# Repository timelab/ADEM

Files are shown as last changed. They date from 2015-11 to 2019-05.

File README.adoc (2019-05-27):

= Timelab ADEM project



The http://www.timelab.org/[Timelab] ADEM project enables cyclists to measure particulate matter (PM~1~ and PM~2.5~). The air quality estimate based on these measurements is displayed on the device, temporarily stored and sent via WiFi to a central data collection service.

The aim of this project is to create a low-cost open-source DIY hardware and firmware kit that is modular and adjustable, can be locally reproduced and repaired.

This git repository hosts the hardware designs, firmware and technical documentation for the ADEM device. You can find the documentation at: https://github.com/timelab/ADEM/tree/master/docs[]

More information related to this project is available from the project's wiki at: http://wiki.timelab.org/wiki/A.D.E.M[]

We welcome feedback and contributions.

ADEM logo

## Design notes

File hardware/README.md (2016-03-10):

# Hardware

The project uses the SparkFun Thing. This ESP8266 based Wi-Fi controller development board runs the A.D.E.M. firmware and conveniently hosts a LiPo battery management system that is key in the mobility aspect of this project. Apart from the headers for the SparkFun Thing, the project's printed circuit board has room for a GPS module, temperature and pressure sensors and connections to external parts like the PPD40NS dust sensor.

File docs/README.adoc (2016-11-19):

= ADEM project documentation
:author: The Timelab ADEM project team
:version: 0.1 draft
:data-uri:
:doctype: book
:encoding: UTF-8
:toc:
:toclevels: 2

Welcome to the ADEM project documentation.

The aim of this project is to create a device that collects air polution data (PM1 and PM2.5 fine dust) and is mounted on bicycles to crowdsource factual air pollution information in and around the city of Ghent, Belgium.

The hardware and firmware design is modular and extendable. The device can be locally reproduced and repaired.

:numbered:
:leveloffset: 1
include::01-getting-started.adoc[]

include::02-arduino-setup.adoc[]

include::03-hardware.adoc[]

include::04-prototype.adoc[]

include::05-firmware-design.adoc[]

:numbered!:
[appendix]
include::0a-questions-and-answers.adoc[]

[appendix]
include::TODO.adoc[]

This is a work in progress so feel free to ask for clarification through GitHub's
https://github.com/timelab/ADEM/issues[issue interface] or even better,
send us updates through GitHub's
https://github.com/timelab/ADEM/pulls[pull request interface].

ADEM logo

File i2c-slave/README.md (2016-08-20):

# i2c-gps
I2C GPS interface for arduino mini pro with low power support

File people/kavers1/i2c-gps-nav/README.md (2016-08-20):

# i2c-gps-nav
MultiWii I2C GPS Nav module with RGB Debug Light / Improved Sonar

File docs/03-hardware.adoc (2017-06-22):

= Hardware

The project uses the SparkFun ESP8266 Thing Development board.

This ESP8266 based WiFi controller development board runs the ADEM firmware and conveniently hosts a LiPo battery management system that is key in the mobility aspect of this project. Apart from the headers for the SparkFun Thing, the project's printed circuit board has room for a GPS module, temperature and pressure sensors and connections to external parts like the PPD40NS dust sensor.

== Bill Of Materials

Listed prices are individual prices, not volume prices.

=== Mandatory components
[options="header"]
|=================================================================================================================
| Function                  | Component / Chip          | Price indication  |   Typical Power Draw - On / (deep sleep)  | Datasheet / Tutorial / Info / Example

| Microcontroller           | SparkFun ESP8266 Thing    | (15.95€ sparkfun) |
https://www.hackster.io/fablabeu/esp8266-thing-by-sparkfun-982bc6[100+mA]  (8mA) | https://cdn.sparkfun.com/datasheets/Wireless/WiFi/ESP8266ThingV1.pdf[datasheet]
https://www.sparkfun.com/products/13231[link] /
https://learn.sparkfun.com/tutorials/esp8266-thing-hookup-guide/all[tutorial]

| Accelerometer             | GY-521 / MPU6050          | (2.83€ banggood)  | 500uA (10uA) |
http://store.invensense.com/datasheets/invensense/MPU-6050_DataSheet_V3%204.pdf[datasheet]
http://playground.arduino.cc/Main/MPU-6050[arduino]

| Barometer                 | BMP180                    | (2.04 € banggood) | 5uA |
https://www.adafruit.com/datasheets/BST-BMP180-DS000-09.pdf[datasheet]

| Battery                   |                           |                   ||
EACHINE 3.7V 500mAh 25C

| Buzzer                    | KY-006                    | (1.44€ banggood)  ||
Xinda active (?) buzzer
https://tkkrlab.nl/wiki/Arduino_KY-006_Small_passive_buzzer_module[info]
http://learn.linksprite.com/arduino/sensors-kit-for-arduino/ky006-buzzer-module/[tutorial]
https://s3.amazonaws.com/linksprite/Arduino_kits/advanced_sensors_kit/KY006+code.pdf[example]

| Fine Dust Meter           | PPD42                     | ($15.90 seeed)                  | http://www.davidholstius.com/tag/ppd42ns/[90mA] |
http://sca-shinyei.com/pdf/PPD42NS.pdf[datasheet]
http://www.takingspace.org/wp-content/uploads/ShinyeiPPD42NS_Deconstruction_TracyAllen.pdf[info]
http://www.howmuchsnow.com/arduino/airquality/grovedust/[tutorial]
http://www.davidholstius.com/2012/06/12/this-side-up/[tips]

| GPS                       | XM37-1612 / GY-NEO6MV2    | (11.66€ banggood) | http://www.resistorpark.com/arduino-gps-gy-neo6mv2/[45uA] (0.02uA) |
https://www.iprototype.nl/docs/gps-LS20031-datasheet-gyneo6mv2.pdf[datasheet]
https://www.u-blox.com/sites/default/files/products/documents/NEO-6_ProductSummary_%28GPS.G6-HW-09003%29.pdf[product sheet]
https://www.u-blox.com/sites/default/files/products/documents/LEA-NEO-MAX-6_HIM_%28UBX-14054794%29.pdf[product family sheet]
https://www.u-blox.com/sites/default/files/products/documents/u-blox6_ReceiverDescrProtSpec_%28GPS.G6-SW-10018%29_Public.pdf[protocol spec]
https://www.u-blox.com/sites/default/files/products/documents/u6-PowerMgt_AppNote_%28GPS.G6-X-10014%29.pdf[power management]

| Humidity                  | HTU21D                    |                   | | https://www.sparkfun.com/products/retired/12064

| RGB Led                   | NeoPixel WS2812 8xled     | (2.40€ banggood)  | https://learn.adafruit.com/adafruit-neopixel-uberguide/power[<60mA] |
High Density Neopixel 8x LED

| Helper microcontroller | Arduino Pro Mini 3.3V | (11.79€ banggood)  |
http://www.whizzy.org/2015/06/howto-very-low-power-usage-on-pro-mini-v2-arduino-clone/[7mA-] http://forum.arduino.cc/index.php?topic=141759.0[9mA]|https://www.arduino.cc/en/Main/ArduinoBoardProMini[info]
|

TOTAL (est.) | | 64.01€ | >200mA | with 500mAh batt -> autonomy: 2,5hrs

|=================================================================================================================

=== Optional components
[options="header"]
|=================================================================================================================
| Function                  | Component / Chip          | Price indication  | Datasheet / Tutorial / Info
| Bluetooth                | HC05 / BC417              | (4.91€ banggood)  |
https://www.olimex.com/Products/Components/RF/BLUETOOTH-SERIAL-HC-06/resources/hc06.pdf[datasheet]

| Memory I2C                | AT24C512C                 | (0.8€ digikey)    |
http://www.atmel.com/devices/AT24C512C.aspx[link]

|=================================================================================================================

ADEM logo

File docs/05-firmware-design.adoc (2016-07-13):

= Firmware design

== Diagram

image::https://drive.google.com/file/d/0B5B2OKuFeGQfSWpKemVRNHZqeDg/view?usp=sharing[alt="Code Diagram", link="https://drive.google.com/file/d/0B5B2OKuFeGQfSFFJQkZjZVJLMGM/view?usp=sharing", align="center"]

== State machine

The state machine is part of the main loop and simply calls the specific state _loop_ code (e.g. +sleep_state()+) or handles a state transition (e.g. +start_to_sleep()+).

The current design is a simplified version, we expect additional states to be required in the future (e.g. for deep sleep, in-house measuring, etc.)

== States

These are the states the main loop controls.

 - START -> SLEEP
 - SLEEP
 - CONFIG
 - GPSTEST
 - COLLECT
 - WIFITEST
 - UPLOAD
 - RESET -> START

The conditional decisions made during a state are performed within the state _loop_. We defined specific functions for these inner loops (e.g. +sleep_state()+ or +collect_state()+).

== State transitions

Additionally when we move from one state to another state in the state machine, we require some things to happen. E.g. enable the sensors, or disconnect the GPS module. For this the state-machine will call specific _transition_ functions (e.g. +start_to_sleep()+ or +sleep_to_gpstest()+).

It is these functions that perform the most work. The state machine itself only directs to a state _loop_ or a transition _call_.

Some of these transitions do not need anything specific to happen.

=== Tasks

During the main loop, the scheduler also preserves time for other tasks to perform actions. These tasks allow e.g. the accelerator sensor to collect new data and update information that can influence the state machine.

Typically each sensor has its own task, however they may not be running the whole time but only in a specific state (e.g. COLLECT):

 - accelerator _(always enabled)_
 - barometer _(enabled in COLLECT state)_
 - gps _(enabled in GPSTEST and COLLECT state)_
 - humidity _(enabled in COLLECT state)_
 - particulate _(enabled in COLLECT state)_

== Pseudo-code

Below was our first design of the state machine. It may help in understand what is going on underneath.
Today this code is properly split into different functions and the state machine is clear an concise.

=== GLOBAL

----
Create accelerometer sensor object
Create barometer sensor object
Create buzzer object
Create gps sensor object
Create humidity sensor object
Create led object
Create particulate sensor object
Create scheduler
----

=== SETUP

----
Set STATE to START

Setup serial output

Create running accelerometer task (1s)
Create suspended barometer task (1m)
Create suspended gps task (1s)
Create suspended humidity task (1m)
Create suspended particulate task (30s)
Create suspended wifiap task
Create suspended wificlient task

Set STATE to SLEEP
----

=== LOOP

----
if STATE == SLEEP:

    if accelerometer.moving:
        Set STATE to GPS_START
        Run gps.begin
        Activate gps task

        Set STATE to GPS_TEST

    else:

        if NOT buffer.empty:
            Set STATE to WIFI_START
            Run wificlient.begin
            Activate wificlient task

            Set STATE to WIFI_TEST

        elif accelerometer.shaking:
            Set STATE to AP_START
            Run wifiap.begin
            Activate wifiap task

            Set STATE to CONFIG

elif STATE == CONFIG:

    if finished or timeout or canceled:
        Set STATE to AP_STOP
        Suspend wifiap task
        Run wifiap.end

        Set STATE to SLEEP

elif STATE == GPS_TEST:

    if accelerometer.moving:
        if gps.ready:
            Set STATE to COLLECT_START
            Run barometer.begin
            Activate barometer task
            Run humidity.begin
            Activate humidity task
            Run particulate.begin
            Activate particulate task

            Set STATE to COLLECT

    else:
        Set STATE to GPS_STOP
        Suspend barometer task
        Run barometer.end
        Suspend humidity task
        Run humidity.end
        Suspend particulate task
        Run particulate.end
        Suspend gps task
        Run gps.end

        Set STATE to SLEEP

elif STATE == COLLECT:

    Write sensor data to datastore

    if NOT accelerometer.moving or NOT gps.ready:
        Set STATE to GPS_TEST

elif STATE == WIFI_TEST:

    if wifi.fix:
        Set STATE to UPLOAD

    if accelerometer.moving OR buffer.empty or wifi.timeout:
        Set STATE to WIFI_STOP
        Suspend wificlient task
        Run wificlient.end

        Set STATE to SLEEP

elif STATE == UPLOAD:

    // Upload action finishes successfully or times out
    Create JSON of X records
    Send to Server
    Empty datastore

    Set STATE to WIFI_TEST

// LED remembers previous state and acts on state-changes
led.update()

scheduler.tick()
----

ADEM logo

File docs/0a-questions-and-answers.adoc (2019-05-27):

= Questions and Answers

== What are we measuring at what frequency ?

[options="header", width="100%"]
|============================================================================================
| Information                                        | Sensor                | Frequency
| Moving                                             | Accelerometer         | interrupt
| Shaking                                            | Accelerometer         | interrupt
| Time                                               | GPS                   | 1 sec
| Location (longitude/latitude)                      | GPS                   | 1 sec
| Particulate matter PM1                             | Particulate           | 20 secs
| Particulate matter PM2.5                           | Particulate           | 20 secs
| Humidity                                           | Humidity              | 1 min
| Temperature                                        | Humidity              | 1 min
| Pressure                                           | Barometer             | 1 min
| Temperature                                        | Barometer             | 1 min
| Altitude (optional)                                | GPS                   | N/A
| Speed (optional)                                   | GPS                   | N/A
| Temperature                                        | Accelerometer         | N/A
| Acceleration                                       | Accelerometer         | N/A
| Gyroscope                                          | Accelerometer         | N/A
|============================================================================================

== Will we use the physical on/off switch of the ESP8266 Thing ?

This is unclear yet. We might add this, but it will not be part of the Minimal Viable Product.

== How will the temperature, humidity and pressure sensors get outside information ?

The casing cannot be completely sealed to get usable humidity and pressure readings. However, we would like to have a water-resistant device to avoid internal condensation and/or rust. It definitely has to sustain all weather conditions. *TBD*

== Can we still make changes to the PCB design ?

At the moment changes to the PCB design are possible. Once we order the first batch of PCB printers, we have to be careful in making new changes.

== What are the essential parts for a release ?

The Minimal Viable Product would consist of the following sensors and compontents:

 - Accelerometer sensor
 - GPS
 - Humidity sensor
 - Barometer sensor
 - Particulate matter sensor

In future revisions (betas) we expect the following additional components:

 - I2C memory
 - Battery
 - Buzzer
 - Bluetooth (unlikely, WIFI and serial should be sufficient)
 - Casing

== Is the JSON interface to the back-end service already defined ?

Not in detail.

We already established that sensor-records will be stored in memory in binary form in a ring-buffer. When the device is not moving, a WIFI fix is obtained and records are uploaded (and buffer emptied). These records will store sensor id information, timing and sensor data. Since the GPS frequency is intermitted with sensor data the records can be properly timestamped.

This ensures efficient use of scarce memory, while retaining augmented information to the back-end.

ADEM logo

== Will the project make use of the newer and faster ESP32 ?

The ESP8266 has its limits. We have ran into problems with the amount of RAM and the available number of I/O pins. In the current stage of the project we are using a secondary processor (AVR) as a serial-to-I2C bridge for the GPS. This could probably be eliminated when switching to ESP32.

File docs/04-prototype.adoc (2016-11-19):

= Prototype design

== Serial baudrate

- For the UART0 serial output, we use the default boot mode baudrate of *74880*.
  This helps to use a single setup for debugging boot mode and firmware.

- For the SoftwareSerial interface to the GPS module, we use the default baudrate of *9600*.
  (Up for debate)

NOTE: For uploading new firmware, the baudrate can go up to *460800*. The baudrate can be selected from the Arduino IDE (Sketch).

== Firmware boot mode information
If you have issues running your firmware, you will see a message like this:

----
 ets Jan  8 2013,rst cause:2, boot mode:(1,6)
----

There is a small overview of the different cases:

.reset causes
[options="header"]
|=========================
| code | reset cause
| 0    | unknown
| 1    | normal boot
| 2    | reset pin
| 3    | software reset
| 4    | watchdog reset
|=========================

.boot mode
[options="header"]
|==============================
| code | description
| 0    | invalid
| 1    | download from UART0
| 2    | invalid
| 3    | boot from flash
| 4-7  | boot from SD-card
|==============================

////
.reset info
[options="header"]
|=================================================================================================
| code | name                    | reason
| 0    | REASON_DEFAULT_RST      | normal startup by power on
| 1    | REASON_WDT_RST          | hardware watch dog reset
| 2    | REASON_EXCEPTION_RST    | exception reset, GPIO status won’t change
| 3    | REASON_SOFT_WDT_RST     | software watch dog reset, GPIO status won’t change
| 4    | REASON_SOFT_RESTART     | software restart ,system_restart , GPIO status won’t change
| 5    | REASON_DEEP_SLEEP_AWAKE | wake up from deep-sleep
| 6    | REASON_EXT_SYS_RST      | external system reset
|=================================================================================================
////

== Pin assignments

Below pins are based on the SparkFun ESP8266 Thing Development board.

.Unfinished Fritzing diagram
image::https://drive.google.com/file/d/0B5B2OKuFeGQfWjY5S21PNXlLc1k/view?usp=sharing[alt="Fritzing diagram", link="https://drive.google.com/file/d/0B5B2OKuFeGQfWjY5S21PNXlLc1k/view?usp=sharing"]

=== Summary

- Pin D0: GPS RX (+ Buzzer)
- Pin D2: I2C SDA
- Pin D4: GPS TX
- Pin D5: NeoPixel (+ Onboard LED)
- Pin D12: PPD42 PM1
- Pin D13: PPD42 PM2.5
- Pin D14: I2C SCL
- Pin D16: (Deep Sleep) -> Usable ?
- Pin A0: PPD42 A

=== Detailed ESP8266

.ESP8266 I²C Header
[options="header"]
|==============================================================================
| Pin Name  | Description                             | Assignment
| GND       | Ground (0V)                             | ->GND line
| 3V3       | 3.3V                                    | ->3V3 line
| SDA (D2)  | I²C SDA (UART1 out: +Serial1+)          | ->SDA bus
| SCL (D14) | I²C SCL                                 | ->SCL bus
|==============================================================================

.ESP8266 UART0 Header
[options="header"]
|==============================================================================
| Pin Name  | Description                             | Assignment
| DTR (D0b) | Data Ready (Auto Reset / D0 Buffer)     |
| TXO (D7)  | UART transmit (+Serial+)                | ->UART0 out
| RXI (D8)  | UART receive (+Serial+)                 | ->UART0 in
| 3V3       | (Not Connected)                         |
| NC        | (Not Connected)                         |
| GND       | Ground (0V)                             | ->UART GND
|==============================================================================

.ESP8266 I/O Pins
[options="header"]
|==============================================================================
| Pin Name  | Description                             | Assignment
| GND       | Ground (0V)                             |
| VIN       | USB 4.5V or LiPo 3.7V                   |
| 5 (D5)    | On-board LED                            |
| 0 (D0)    |                                         | ->NeoPixel
| 4 (D4)    |                                         | ->GPS TX
| 13 (D13)  |                                         | ->PPD42 +PM25_SENSOR+
| 12 (D12)  |                                         | ->PPD42 +PM1_SENSOR+
| XPD (D16) | (Deep Sleep)                            |
| ADC (A0)  | (10-bit 1V)                             | ->PPD42 +A_SENSOR+
| EN        | Enable PIN                              |
|==============================================================================

=== Detailed Components

.PPD42NS (Fine dust meter)
[options="header"]
|==============================================================================
| Pin Name  | Description                             | Assignment
| 1         | Ground                                  | ->GND line
| 2         | Output P2 +PM25_SENSOR+                 | ->D13
| 3         | Vcc (5V, 90mA)                          | ->3V3 line
| 4         | Output P1 +PM1_SENSOR+                  | ->D12
| 5         | Input (T1) +A_SENSOR+, threshold for P2 | ->ADC
|==============================================================================

.GY-NEO6MV2 (GPS)
[options="header"]
|==============================================================================
| Pin Name  | Description                             | Assignment
| VCC       |                                         | ->3V3 line
| RX        |                                         |
| TX        |                                         | ->D4
| GND       | Ground (0V)                             | ->GND line
|==============================================================================

.NeoPixel (LED)
[options="header"]
|==============================================================================
| Pin Name  | Description                             | Assignment
| GND       | Ground (0V)                             | ->GND line
| Din       | Input signal                            | ->D0
| 5V        | Vcc (5V, ?mA)                           | ->3V3 line
|==============================================================================

.BMP180 (Barometer)
[options="header"]
|==============================================================================
| Pin Name  | Description                             | Assignment
| VIN       |                                         | ->3V3 line
| GND       |                                         | ->GND line
| SCL       |                                         | ->SCL bus
| SDA       |                                         | ->SDA bus
|==============================================================================

.HTU21D (Humidity/Temperature meter)
[options="header"]
|==============================================================================
| Pin Name  | Description                             | Assignment
| CL        |                                         | ->SCL bus
| DA        |                                         | ->SDA bus
| -         |                                         | ->GND line
| +         |                                         | ->3V3 line
|==============================================================================

.IGT/MPU (Accelerometer)
[options="header"]
|==============================================================================
| Pin Name  | Description                             | Assignment
| INT       |                                         |
| AD0       |                                         |
| XCL       |                                         |
| XDA       |                                         |
| SDA       |                                         | ->SDA bus
| SCL       |                                         | ->SCL bus
| GND       |                                         | ->GND line
| VCC       |                                         | ->3V3 line
|==============================================================================

=== Constraints

During testing we discovered some constraints to used pins.

NOTE: TODO: Describe the known issues here ? (Lieven)

ADEM logo

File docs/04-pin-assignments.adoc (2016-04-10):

= ESP8266 pin assignments

== Breadboard prototype Dag

Below pins are based on the SparkFun ESP8266 Thing.

.ESP8266 I²C Header
[options="header"]
|==============================================================================
| Pin Name  | Description                             | Assignment
| GND       | Ground (0V)                             | ->GND line
| 3V3       | 3.3V                                    | ->3V3 line
| SDA (D2)  | I²C SDA (UART2 out: +Serial1+)          | ->SDA bus
| SCL (D14) | I²C SCL                                 | ->SCL bus
|==============================================================================

.ESP8266 UART1 Header
[options="header"]
|==============================================================================
| Pin Name  | Description                             | Assignment
| DTR       | Data Ready (Auto Reset / D0 Buffer)     |
| TXO (D7)  | UART transmit (+Serial+)                | ->UART1 out
| RXI (D8)  | UART receive (+Serial+)                 | ->UART1 in
| 3V3       | (Not Connected)                         |
| NC        | (Not Connected)                         |
| GND       | Ground (0V)                             | ->UART GND
|==============================================================================

.ESP8266 I/O Pins
[options="header"]
|==============================================================================
| Pin Name  | Description                             | Assignment
| GND       | Ground (0V)                             |
| VIN       | USB 4.5V or LiPo 3.7V                   |
| 5 (D5)    | On-board LED ->Free                     |
| 0 (D0)    |                                         | ->NeoPixel
| 4 (D4)    |                                         | ->GPS TX
| 13 (D13)  |                                         | ->PPD42 +PM25_SENSOR+
| 12 (D12)  |                                         | ->PPD42 +PM10_SENSOR+
| XPD (D16) | (Deep Sleep)                            |
| ADC (A0)  | (10-bit 1V)                             | ->PPD42 +A_SENSOR+
| EN        | Enable PIN                              |
|==============================================================================

.Unassigned
 - BT_RX
 - BT_TX
 - INT
 - BUZZ

== Components

.PPD42NS (Fine dust meter)
[options="header"]
|==============================================================================
| Pin Name  | Description                             | Assignment
| 1         | Ground                                  | ->GND line
| 2         | Output P2 +PM25_SENSOR+                 | ->D13
| 3         | Vcc (5V, 90mA)                          | ->3V3 line
| 4         | Output P1 +PM10_SENSOR+                 | ->D12
| 5         | Input (T1) +A_SENSOR+, threshold for P2 | ->ADC
|==============================================================================

.GY-NEO6MV2 (GPS)
[options="header"]
|==============================================================================
| Pin Name  | Description                             | Assignment
| VCC       |                                         | ->3V3 line
| RX        |                                         |
| TX        |                                         | ->D4
| GND       | Ground (0V)                             | ->GND line
|==============================================================================

.NeoPixel (LED)
[options="header"]
|==============================================================================
| Pin Name  | Description                             | Assignment
| GND       | Ground (0V)                             | ->GND line
| Din       | Input signal                            | ->D0
| 5V        | Vcc (5V, ?mA)                           | ->3V3 line
|==============================================================================

.BMP180 (Barometer)
[options="header"]
|==============================================================================
| Pin Name  | Description                             | Assignment
| VIN       |                                         | ->3V3 line
| GND       |                                         | ->GND line
| SCL       |                                         | ->SCL bus
| SDA       |                                         | ->SDA bus
|==============================================================================

.HTU21D (Humidity/Temperature meter)
[options="header"]
|==============================================================================
| Pin Name  | Description                             | Assignment
| CL        |                                         | ->SCL bus
| DA        |                                         | ->SDA bus
| -         |                                         | ->GND line
| +         |                                         | ->3V3 line
|==============================================================================

.IGT/MPU (Accelerometer)
[options="header"]
|==============================================================================
| Pin Name  | Description                             | Assignment
| INT       |                                         |
| AD0       |                                         |
| XCL       |                                         |
| XDA       |                                         |
| SDA       |                                         | ->SDA bus
| SCL       |                                         | ->SCL bus
| GND       |                                         | ->GND line
| VCC       |                                         | ->3V3 line
|==============================================================================

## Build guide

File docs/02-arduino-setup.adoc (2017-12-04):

= Arduino setup

The firmware is written in Arduino.

== Installing the ESP8266 Arduino Addon

Follow the SparkFun tutorial on how to install the ESP8266 to your Arduino IDE:
https://learn.sparkfun.com/tutorials/esp8266-thing-hookup-guide/installing-the-esp8266-arduino-addon

== Cloning the ADEM GitHub repository

=== Installing Git

- Sign-up for a GitHub account at https://github.com/[]

- Install git on your PC

  * For Debian/Ubuntu:

    $ sudo apt-get install git

  * For Fedora/RHEL/CentOS:

    $ sudo yum install git

  * For Windows:

    1. Download and install from https://git-scm.com/downloads

    2. If you are editing code, make sure that your editor or IDE does not modify line-endings (this would make it look like unmodified files have been changed, and/or results in extra newlines under Linux).
       JetBrains IntelliJ IDEA is an example of a multi-platform IDE which can work with GitHub, and provide structure to the codebase.

- Set your GitHub and e-mailadress

  $ git config --global user.name "John Doe"
  $ git config --global user.email johndoe@example.com

=== Cloning the repository

You can make a local copy of the ADEM project code by running the following git command:

  $ git clone git@github.com:timelab/ADEM.git

== Contributing code

=== Forking
If you have a github account, you can contribute code to the ADEM project. Go to https://github.com/timelab/ADEM and *fork* the project to your GitHub profile. Then add it as a separate remote (stored in _.git/config_).

    $ git remote add yourgitusername https://github.com/yourgitusername/ADEM

If you use SSH keys, use:

    $ git remote add yourgitusername git@github.com:yourgitusername/ADEM.git

Update:

    $ git remote update

This way you can create pull-requests by modifying your local copy and pushing it to your personal GitHub profile.
Afterwards, the GitHub web-interface proposes to create a pull-request. It helps if you use different branches for pushing changes.

More information regarding the use of Git is available from: http://www.git-scm.com/book/en/v1/Git-Basics
The forking and contributing aspect is handled on: https://www.git-scm.com/book/en/v2/GitHub-Contributing-to-a-Project

More information regarding the use of GitHub is available from: https://guides.github.com/activities/hello-world/

=== Git daily use

Show the status of your local repository, you can do this any time:

    $ git status

When you want to add or change code, *make a new branch first*:

    $ git checkout -b <name of your branch>

Edit the files in you local copy with your editor of choice. After creating a new file or folder, add it so git can start tracking it:

    $ git add <file>

Remove a file (also from the repository after commit!)

    $ git rm <file>

Commit your changes to your local copy and add your commit message on the top of the file:

    $ git commit -v

Now upload (_Push_) it to your online forked Github repo:

    $ git push --set-upstream <user> <name of your branch>

Go to https://github.com/timelab/ADEM and click *Compare & pull request*. If it fixes an issue, add _Fixes #issuenumber_ as comment. Click ''Create pull request''

What has happenend:

    $ git log

Get the changes from the online repository and merge them into local files

    $ git pull --rebase origin master

== Build the firmware

=== Installing required libraries in Arduino

In order to build project code using Arduino Sketch IDE, you need to ensure that Arduino can find the libraries we use.

You will have to overwrite the Arduino "Sketchbook location" with the path to where your ADEM folder is. You can set this under File -> Preferences.
If you are already using Arduino for other projects, alternatively, you can check out the ADEM repository to a subfolder of the default Sketchbook location.

=== Using make as alternative to Arduino IDE

==== Using make for building Arduino code

The project also provides a Makefile with the instructions to build, flash/upload and monitor the device.

You can build the source code by doing:

  $ make build

You can also build the i2c-slave code (used for the GPS) by doing:

  $ make build SKETCH=i2c-slave/i2c-slave.ino

Other test code can be build as well using:

  $ make build SKETCH=people/dagwieers/gps_test/gps_test.ino

Once this is done, you can flash your device using:

  $ make flash

or

  $ make flash SKETCH=i2c-slave/i2c-slave.ino

You can do both in one go by using the `upload` target, just like in the Arduino Sketch IDE:

  $ make upload

or

  $ make upload SKETCH=i2c-slave/i2c-slave.ino

You can also influence the serial port and baud rate used for flashing:

  $ make upload SERIAL_PORT=/dev/ttyUSB0 FLASH_BAUD=115200

The default serial port for flashing depends on the HWTYPE but usually is `/dev/ttyUSB0`, the default baud rate for flashing depends on the hardware.

==== Connecting to the device

The most "stable" way to connect to your device is unfortunately still using the Serial Monitor of the Arduino Sketch IDE. This has something to do with the serial port initialization and baud rate. Once the port is initialized in the Arduino IDE (at 74880 baud), you can exit the IDE and switch to using this:

  $ make monitor

or:

  $ make serial

The first command is using the GNU screen tool for connecting to the device, and this enables also sending characters to the device. The second command is a simple `cat` to your device. You can influence the device and baud rate using:

  $ make monitor SERIAL_PORT=/dev/ttyUSB0 SERIAL_BAUD=74880

The default serial port for monitoring is `/dev/ttyUSB0` and the default baud rate for monitoring is `38400`. Use  `CTRL+a` and then `k` to exit monitor.

FIXME: apparently you can use 'tail' to monitor, if you set the the terminal line settings correctly using stty; ex. stty -F /dev/serial/by-id/usb-1a86_USB2.0-Serial-if00-port0 cs8 74880 ignbrk -brkint -icrnl -imaxbel -opost -onlcr -isig -icanon -iexten -echo -echoe -echok -echoctl -echoke noflsh -ixon -crtscts
FIXME: untested with ESP8266 (tested with Arduino Nano at different baud rate)

==== Building with DEBUG enabled

We also provide a way to enable debugging for your build.

  $ make CFLAGS=-DDEBUG

This incidentally is also the default compilation flag. However some libraries have their own debugging flag.

  $ make CFLAGS="-DDEBUG_SCHED -DDEBUG_GPS"

If you want to build without DEBUG mode, you can simply do:

  $ make CFLAGS=

==== Building, flashing and monitoring

Now for convenience you can do building, flashing and monitoring at once:

 $ make upload monitor

== External libraries

All external libraries we depend upon for the firmware are included in the repository. This to ensure that we have reproducible builds and can integrate easily with Travis CI. Hence there is no need to download them separately.

The following external libraries are currently being used:

Adafruit NeoPixel::
  - Version: 1.0.6
  - License: LGPL v3
  - URL: https://github.com/adafruit/Adafruit_NeoPixel

ArduinoJson::
  - Version: 5.6.7
  - License: MIT
  - URL: https://github.com/bblanchon/ArduinoJson

espsoftwareserial::
  - Version: 3.1.0
  - License: LGPL v2.1+
  - URL: https://github.com/plerup/espsoftwareserial

TinyGPS++::
  - Version: 0.94b
  - License: LGPL v2.1+
  - URL: https://github.com/mikalhart/TinyGPSPlus

WiFiManager::
  - Version: 0.12
  - License: MIT
  - URL: https://github.com/tzapu/WiFiManager

ADEM logo

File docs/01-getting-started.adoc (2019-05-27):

= Getting started with ADEM

== Project information

Project website (Dutch)::
    http://ik-adem.be/

Wiki website (Dutch)::
    http://wiki.timelab.org/wiki/A.D.E.M

Project contact::

....
Timelab vzw
Kogelstraat 34
9000 Gent, Belgium
Telephone: +32 9 391 96 10
Email: ja@ik-adem.be
....

== Project collaboration

GitHub repository::
    https://github.com/timelab/ADEM

Google Drive::
    https://drive.google.com/open?id=0B5B2OKuFeGQfT0p0bUllNUdlb0k

== Technical information

Technical documentation::
    https://github.com/timelab/ADEM/tree/master/docs

ESP8266 book::
    http://neilkolban.com/tech/esp8266/

ESP8266 wiki::
    https://github.com/esp8266/esp8266-wiki/wiki

ADEM logo

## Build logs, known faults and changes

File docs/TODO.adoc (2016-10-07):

= TODO
Please update the below table with detailed sub-tasks, both those that are
completed and still on-going.

== Hardware status
[options="header", width="100%"]
|============================================================================================
| Task                                               | Status                | Owner
| Hardware selection                                 | Completed             | Koen
| Testing individual sensors                         | Completed             | Koen
| Breadboard prototype                               | Completed             | Dag
| Add breadboard prototype design (fritzing)         | Completed             | Dag
| PCB design                                         | Ongoing ?             | Koen
|============================================================================================

== Firmware status
[options="header", width="100%"]
|============================================================================================
| Task                                     | Release | Status                | Owner
| Component / libraries                    |         |                       |
| - Scheduler                              | alpha   | Completed             | Koen
| - GPS library (SwSerial)                 | alpha   | Completed             | Dag / Lieven
| - Dust meter (PPD42)                     | alpha   | Completed             | Lieven
| - Temperature / Humidity (HTU21D)        | alpha   | Completed             | Koen
| - Barometer (BMP180)                     | alpha   | Completed             | Koen
| - LED (NeoPixel)                         | alpha   | Completed             | Stijn / Dag
| - Accelerometer (MPU6050)                | alpha   | Ongoing               | Koen
| - I2C GPS                                | alpha   | Ongoing               | Koen
| - Battery (Lipo)                         | beta    | Ongoing               | Dag
| - Buzzer                                 | beta    | Ongoing               | Dag
| Code integration                         |         |                       |
| - Modularity                             | alpha   | Completed             | Koen / Lieven
| - Pseudo-code                            | alpha   | Completed             | Lieven / Dag
| - Cleanup / library naming               | alpha   | Completed             | Dag
| - Travis CI                              | alpha   | Completed             | Dag
| - State machine                          | alpha   | Completed             | Lieven / Dag / Koen
| - DEBUG mode                             | alpha   | Completed             | Dag
| - Serial input to state machine (debug)  | alpha   | Completed             | Dag
| - PlatformIO support                     | beta    | Completed             | Dag
| - Code conformity                        | beta    | Ongoing               | Dag
| WiFi integration                         |         |                       |
| - Wi-Fi Client (upload)                  | alpha   | Ongoing               | Marco / Dag
| - Upload code                            | alpha   | Ongoing               |
| - Wi-Fi AP (setup)                       | beta?   | Ongoing               | Marco / Dag
| - Config website                         | beta?   | Ongoing               | Marco / Dag
| - OTA firmware updates                   | beta?   | TBD                   |
| Datastore                                |         |                       |
| - Internal memory                        | alpha   | Completed             | Koen
| - I2C memory                             | beta    | TBD                   |
| - Filesystem                             | beta?   | TBD                   |
| Shaking/moving detection                 | alpha   | Ongoing               | Koen
| Power management                         | beta    | TBD                   |
| - Disable on-board power LED             | beta    | TBD                   |
| - Deepsleep implementation               | beta    | TBD                   |
| DEMO mode                                |         |                       |
| - JSON support                           | alpha   | Completed             | Dag
| - Captive portal                         | alpha   | Completed             | Dag
| - Fancy web interface                    | alpha   | TBD                   | Arnaud
| Troubleshoot existing FIXMEs             | beta?   | TBD                   | You ?
|============================================================================================

== Known issues
[options="header", width="100%"]
|============================================================================================
| Issue                                                                | Component
| Barometer calibration hangs when started first (I2C?)                | barometer_BMP085
| NeoPixel brightness does not seem to have effect                     | led_NeoPixel
| PPD42 measurements are off                                           | particulate_PPD42
| There is no free GPIO for buzzer                                     | buzzer_passive
|============================================================================================

== Documentation status
[options="header", width="100%"]
|============================================================================================
| Task                                               | Status                | Owner
| Pin assignments                                    | Completed             | Koen / Dag
| Document pseudo-code                               | Completed             | Dag
| Create state diagram and conditions                | Completed             | Dag
| Add technical questions and answers                | Completed             | Dag
| Update project license to LGPLv3                   | Completed             | Dag
| Read the documentation and test procedures         | TBD                   | You ?
|============================================================================================

== Backend status
[options="header", width="100%"]
|============================================================================================
| Task                                               | Status                | Owner
| Architecture                                       | TBD                   |
|============================================================================================

ADEM logo

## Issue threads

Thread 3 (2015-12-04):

Use the Scheduler library

lebeno, 2015-12-04:
We could use the Scheduler library to create separate "threads":
* sendBuffer()
* GPS data reading and processing
* analog sampling of dust sensor

lebeno, 2016-03-02:
kavers1 is working on a scheduling library

kavers1, 2016-03-07:
First version is available. Although it may crash when turning logging on, it functioned well for over 12 hours when just doing its job. Need further testing but is ready for initial use and keep the project going.

dagwieers, 2016-03-20:
@kavers1 We are having issues using SoftwareSerial (GPS) together with interrupt handlers for the PPD42.I assume that when we are receiving GPS data interrupts for PPD42 are disabled ? We always get 0 (both for PM10 as PM25). It only works if we stop using SoftwareSerial.

Does the scheduler somehow help with this ? Or do we plan to use the real UART for the communication with the GPS ?
Can we maybe use an i2c-based GPS module instead (e.g. http://www.flytron.com/sensors/180-i2c-gps-for-multiwii-and-others.html) ?

dagwieers, 2016-04-14:
We can close this issue. The TickerSchedlr is integrated in the main code now.
Next step is to implement the pseudo-code using TickerSchedlr.

Closed 2016-04-14.

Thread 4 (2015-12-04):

Interrupt for PPD42NS on GPIO 12 and 13 do not work

lebeno, 2015-12-04:
GPIO 12 and 13 begin pulled down by PPD42NS of manually does not seem to call the attached interrupt funtions. Even tried manually by shorting to ground. PPD42NS pulls down to about 1V. Is that low enough?

lebeno, 2016-03-02:
works in ADEM/arduino/libraries/Ppd42

Closed 2016-03-02.

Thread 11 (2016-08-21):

i2c-gps does not build

dagwieers, 2016-08-21:
I get the following error when building i2c-gps:
```
i2c-gps:934: error: expected constructor, destructor, or type conversion before ';' token
 blink_update();
               ^
i2c-gps:938: error: expected unqualified-id before 'if'
 if (_watchdog_timer != 0)
 ^
exit status 1
expected constructor, destructor, or type conversion before ';' token
```

dagwieers, 2016-08-21:
I think it is related to the following statements:

    #pragma region while serial available

    #pragma endregion

kavers1, 2016-08-21:
Dag,

bij mij compileerd dit zonder enige wijziging. Welke versie van arduino
tool chain gebruiken we ? Ik ben op 1.6.7 (niet de laatste weet ik)

/De schets gebruikt 6.986 bytes (22%)  programma-opslagruimte. Maximum
is 30.720 bytes.//
//Globale variabelen gebruiken 478 bytes (23%) van het dynamisch
geheugen. Resteren 1.570 bytes voor lokale variabelen. Maximum is 2.048
bytes.

/Heb je bij het compileren het board veranderd ? en eventueel het
library path verzet naar de arduino libraries ? (moet ik doen op windows
weet niet of dat bij linux nodig is)

koen

Op 21/08/2016 om 9:49 schreef Dag Wieers:
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

dagwieers, 2016-09-28:
Problem is related to a missing/incomplete config.h.

Closed 2016-09-28.

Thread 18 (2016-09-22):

Add date/time of last sensor data in DEMO page

dagwieers, 2016-09-22:
We should probably add a date/time to the DEMO page, and only update it when new sensor data is pulled from the device. This would make it more clear when the device is no longer showing the real-time measurements.

We could also indicate when measurements have stopped (for whatever reason).

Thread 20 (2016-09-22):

Infrequent crashes

dagwieers, 2016-09-22:
In DEMO made running overnight, I experienced one crash.

```
Serial communication... OK
Initializing LED... OK
Initializing scheduler... OK
Initializing barometer sensor... OK
Initializing humidity sensor... OK
Initializing particulate sensor... OK

=> Please connect to SSID: ADEM-9087009
=> And surf to: http://192.168.4.1/

Exception (29):
epc1=0x4000e1c3 epc2=0x00000000 epc3=0x00000000 excvaddr=0x00000018 depc=0x00000000

ctx: sys
sp: 3ffffc80 end: 3fffffb0 offset: 01a0

>>>stack>>>
3ffffe20:  401030a9 3ffef580 3ffeff80 00000000
3ffffe30:  40219ca9 40219be6 3fff3c7c 40103238
3ffffe40:  00000018 3ffeff80 3ffefefc 00000000
3ffffe50:  40219d40 3ff20a00 3fff3c7c 3ffed0be
3ffffe60:  3ffed0a4 3ffec3d8 3ffec3d8 3ffed0a4
3ffffe70:  3ffed0be 0000002c 00000004 401004f4
3ffffe80:  3ffed0ae 3fff403c 40216a93 3ff20a00
3ffffe90:  3fff3c7c 3fff97e4 00000015 40216965
3ffffea0:  3ffec3fc 4010760c 3fffc258 4000050c
3ffffeb0:  40000f83 00000030 00000010 ffffffff
3ffffec0:  40000f3d 00000023 00000000 3fffd9d0
3ffffed0:  00000000 00000000 00000000 fffffffe
3ffffee0:  ffffffff 3fffc6fc 00000000 3fffdab0
3ffffef0:  00000000 3fffdad0 3fff2344 00000030
3fffff00:  3ffed700 00000000 00000036 401004d8
3fffff10:  4021df01 ffffffd6 00000000 40107a98
3fffff20:  40216201 3ffed0a4 3ffef580 3fff3c7c
3fffff30:  00000000 3ffed0ae 3ffed0c8 40106e56
3fffff40:  40211660 00000000 3ffed0ae 3ffed0a4
3fffff50:  0000002e 00000000 3fff403c 3ffed098
3fffff60:  00000000 00000036 40211292 3ffef580
3fffff70:  3ffed098 3fffdcc0 3ffebbc0 3fff3f24
3fffff80:  3ffed0b4 00000040 00000000 3fff2350
3fffff90:  40210bdf 3fffdab0 00000000 4020e877
3fffffa0:  3ffebbc0 40000f49 3fffdab0 40000f49
<<<stack<<<
```

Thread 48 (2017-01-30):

wrong values for voltages

lebeno, 2017-01-30:
Voltage measurements return incorrect values like
`{"Sensor":"Battery","VCC":65535,"Voltage":64.00}`

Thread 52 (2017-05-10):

building the GPS I2C slave code fails with /bin/avr-g++: no such file or directory

lebeno, 2017-05-10:
```
$ make build SKETCH=i2c-slave/i2c-slave.ino
...
fork/exec /bin/avr-g++: no such file or directory
Makefile:73: recipe for target 'build' failed
make: *** [build] Error 1
```

lebeno, 2017-05-10:
This is a problem generated by installing Arduino AVR Boards version 1.6.18 because it deletes the AVR tools of version 1.6.17 but does not download or install new tools for version 1.6.18. Revert back to 1.6.17:

1. Start the Arduino IDE:
`$ ~/arduino-1.8.2/arduino`
2. Tools > Board > Board Manager ... > select the Arduino AVR Boards
3. Select version 1.6.17 and Install.
4. Close the Boards Manager window and the Arduino IDE

Closed 2017-05-10.

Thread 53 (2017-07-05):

build fails with error "esp8266: Unknown package"

lebeno, 2017-07-05:
```
$ make build
mkdir -p "/home/lieven/ADEM/ADEM/Build"
"/home/lieven/ADEM/ADEM/Arduino/arduino-builder" --compile \
	--fqbn=esp8266:esp8266:thing \
	--verbose --debug-level=9 --prefs=build.debug_level="-DDEBUG -DDEBUG_OUTPUT=Serial" --prefs=tools.ctags.path="/home/lieven/ADEM/ADEM/Arduino/tools-builder/ctags/5.8-arduino11" \
	--hardware="/home/lieven/ADEM/ADEM/Arduino/hardware" \
	--hardware="/home/lieven/ADEM/ADEM/arduino15/packages" \
	--tools="/home/lieven/ADEM/ADEM/Arduino/tools" \
	--tools="/home/lieven/ADEM/ADEM/arduino15/packages" \
	--libraries="adem/libraries/" \
	--build-path="/home/lieven/ADEM/ADEM/Build" \
	adem/adem.ino
esp8266: Unknown package
Makefile:73: recipe for target 'build' failed
make: *** [build] Error 1

```

lebeno, 2017-07-05:
Apparently my Arduino environment 'lost' the libraries for the ESP8266 board.

Solved by Installing the ESP8266 Arduino Addon. See instructions under **Installing the ESP8266 Arduino Addon** from `02-arduino-setup.adoc`.

Closed 2017-07-05.

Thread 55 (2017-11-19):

add state to state machine te handle no network conneected

kavers1, 2017-11-19:
in the upload state we try to connect to the known networks. If not successful we keep on trying and as such will drain the battery. It is better to add a state to reflect the failure. Stay in the state untill the next measurements are ready to be uploaded

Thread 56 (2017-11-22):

add demo.ino as state to adem.ino

lebeno, 2017-11-22:
The demo mode is currently a separate project. It should better reside in a separate demo folder as required by the Arduino IDE.

We want to integrate the demo.ino code into the adem.ino project as a separate state that can be started from the setup page shown in the AP mode of the ADEM project.

lebeno, 2017-11-22:
moved demo.ino to subfolder demo in commit fd995e8

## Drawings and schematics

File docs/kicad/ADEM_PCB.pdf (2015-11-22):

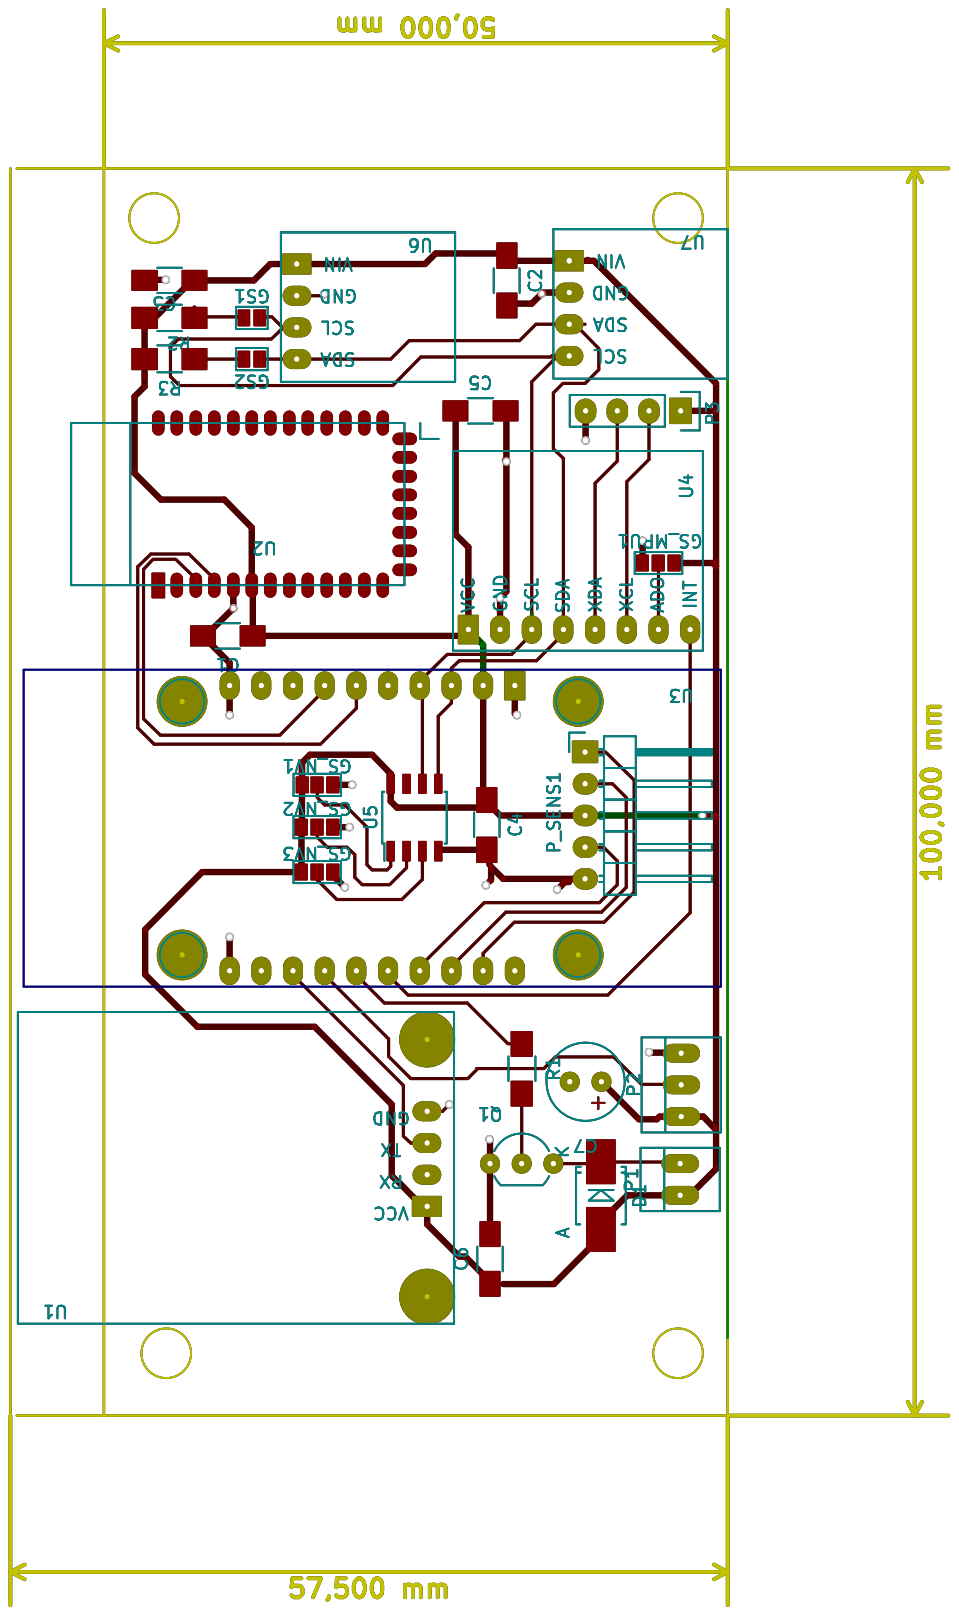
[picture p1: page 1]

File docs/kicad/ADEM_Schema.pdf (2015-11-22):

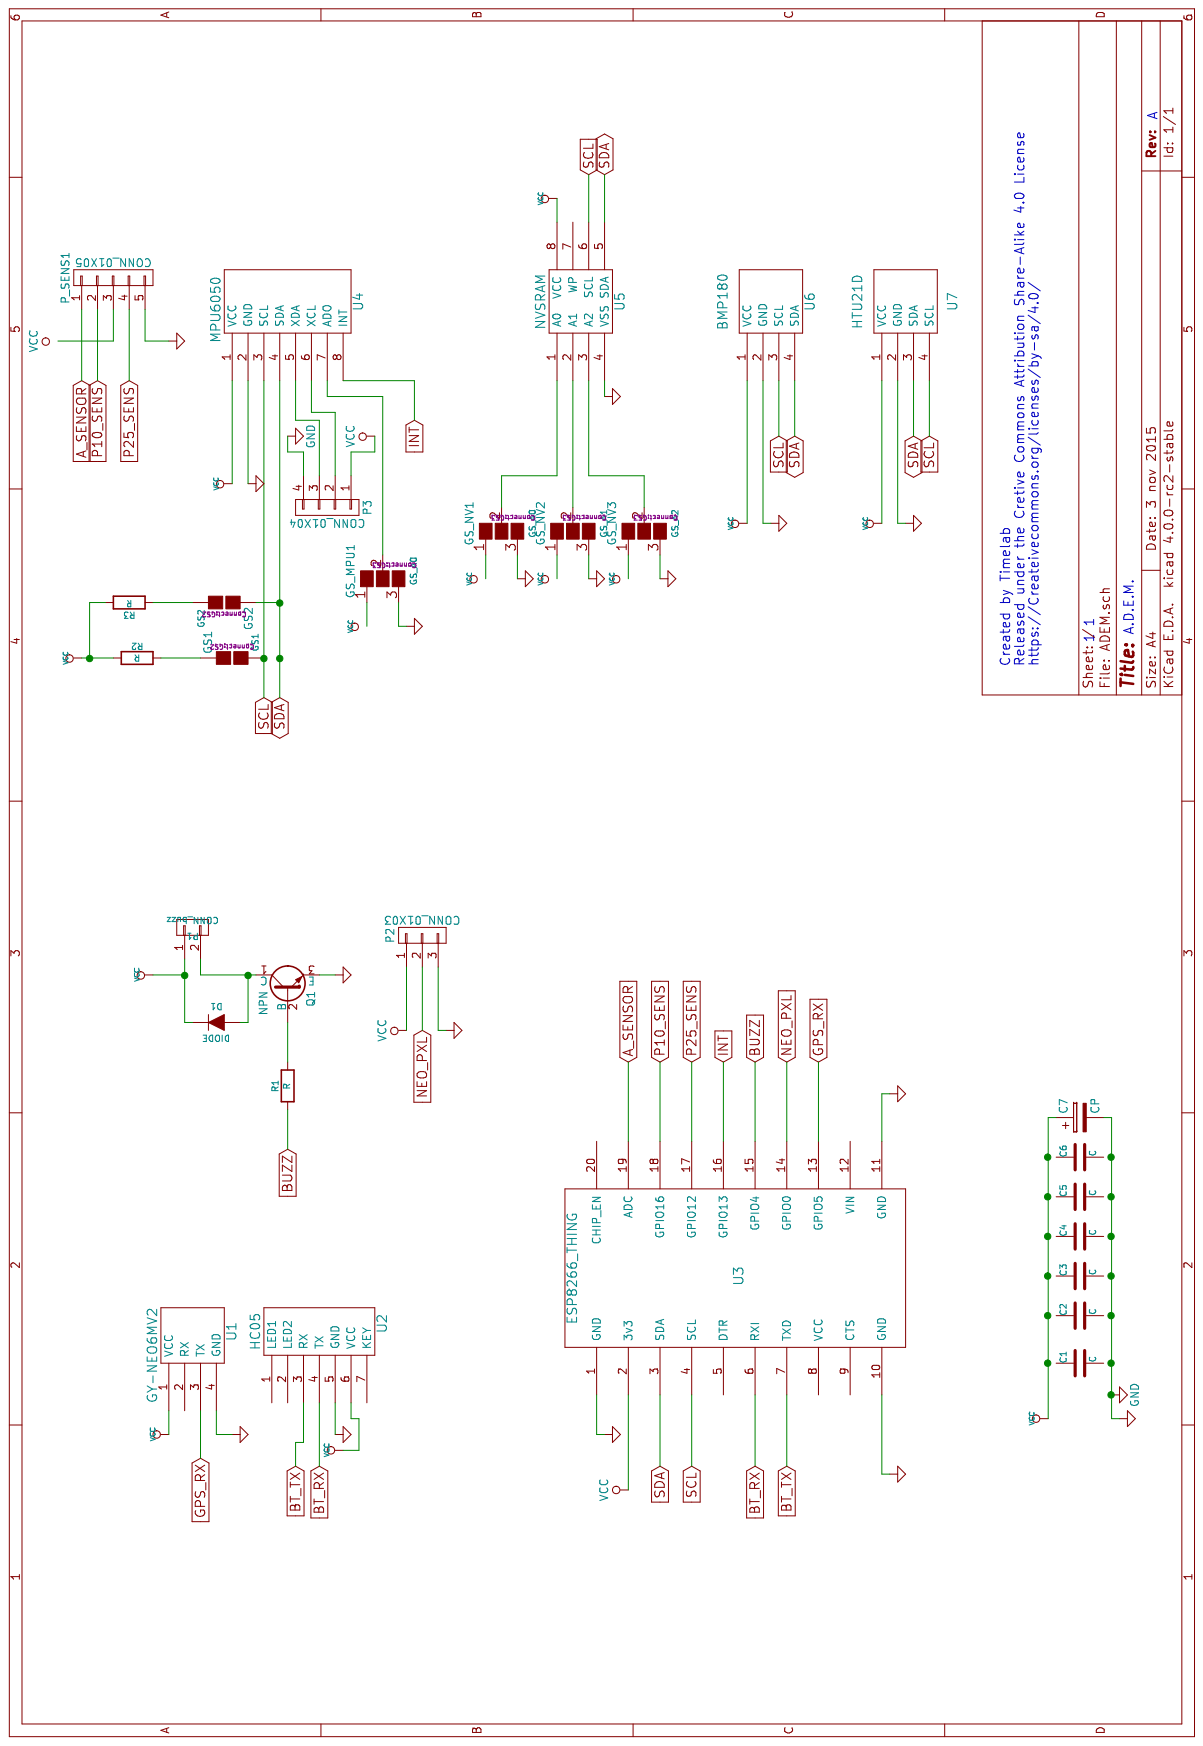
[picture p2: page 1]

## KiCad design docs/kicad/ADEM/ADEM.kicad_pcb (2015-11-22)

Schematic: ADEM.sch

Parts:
C1, C2, C3, C4, C5, C6: C; C_1206_HandSoldering
C7: CP; Elko_vert_11.2x6.3mm_RM2.5
D1: DIODE; SMB_Handsoldering
GS1: GS1; GS2
GS2: GS2
GS_MPU1: GS_A0; GS3
GS_NV1: GS_A0; GS3
GS_NV2: GS_A1; GS3
GS_NV3: GS_A2; GS3
P1: CONN_buzz; PINHEAD1-2
P2: CONN_01X03; PINHEAD1-3
P3: CONN_01X04; Pin_Header_Straight_1x04
P_SENS1: CONN_01X05; Pin_Header_Angled_1x05
Q1: NPN; TO-92_Inline_Wide
R1, R2, R3: R; R_1206_HandSoldering
U1: GY-NEO6MV2
U2: HC05; HC-05
U3: ESP8266_THING
U4: MPU6050
U5: NVSRAM; SOIC-8_3.9x4.9mm_Pitch1.27mm
U6: BMP180
U7: HTU21D

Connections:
A_SENSOR: P_SENS1.1, U3.19 (ADC)
BT_RX: U2.4 (TX), U3.6 (RXI)
BT_TX: U2.3 (RX), U3.7 (TXD)
BUZZ: R1.1, U3.15 (GPIO4)
GND: C1.2, C2.2, C3.2, C4.2, C5.2, C6.2, C7.2, GS_MPU1.3 (G3), GS_NV1.3 (G3), GS_NV2.3 (G3), GS_NV3.3 (G3), P2.3, P3.4, P_SENS1.5, Q1.1, U1.4 (GND), U2.5 (GND), U3.1 (GND), U3.10 (GND), U3.11 (GND), U4.2 (GND), U5.4 (VSS), U6.2 (GND), U7.2 (GND)
GPS_RX: U1.3 (TX), U3.13 (GPIO5)
INT: U3.16 (GPIO13), U4.8 (INT)
NEO_PXL: P2.2, U3.14 (GPIO0)
unnamed: D1.1, P1.2, Q1.3
unnamed: GS1.1 (G1), R2.2
unnamed: GS2.2 (G2), R3.1
unnamed: GS_MPU1.2 (G2), U4.7 (ADO)
unnamed: GS_NV1.2 (G2), U5.1 (A0)
unnamed: GS_NV2.2 (G2), U5.2 (A1)
unnamed: GS_NV3.2 (G2), U5.3 (A2)
unnamed: P3.2, U4.6 (XCL)
unnamed: P3.3, U4.5 (XDA)
unnamed: Q1.2, R1.2
P10_SENS: P_SENS1.2, U3.18 (GPIO16)
P25_SENS: P_SENS1.4, U3.17 (GPIO12)
SCL: GS1.2 (G2), U3.4 (SCL), U4.3 (SCL), U5.6 (SCL), U6.3 (SCL), U7.4 (SCL)
SDA: GS2.1 (G1), U3.3 (SDA), U4.4 (SDA), U5.5 (SDA), U6.4 (SDA), U7.3 (SDA)
VCC: C1.1, C2.1, C3.1, C4.1, C5.1, C6.1, C7.1, D1.2, GS_MPU1.1 (G1), GS_NV1.1 (G1), GS_NV2.1 (G1), GS_NV3.1 (G1), P1.1, P2.1, P3.1, P_SENS1.3, R2.1, R3.2, U1.1 (VCC), U2.6 (VCC), U3.2 (3v3), U4.1 (VCC), U5.8 (VCC), U6.1 (VCC), U7.1 (VCC)

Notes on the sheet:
Created by Timelab Released under the Cretive Commons Attribution Share-Alike 4.0 License https://Createivecommons.org/licenses/by-sa/4.0/
A.D.E.M.

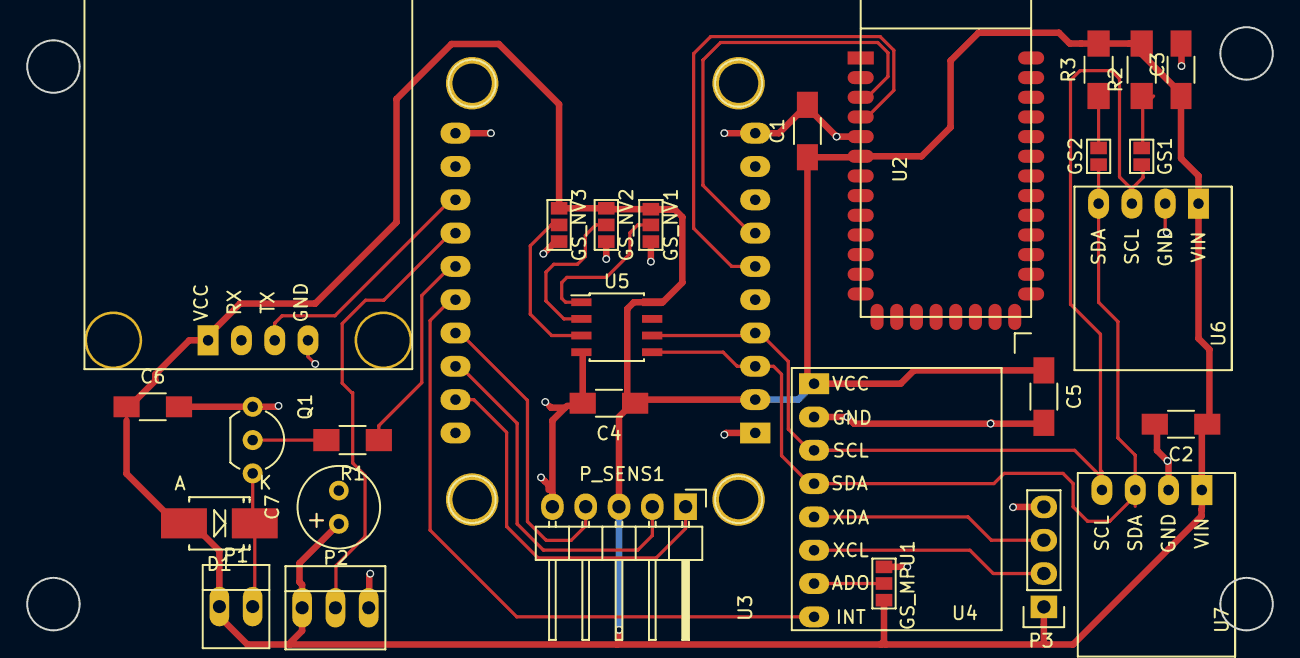
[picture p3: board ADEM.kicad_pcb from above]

Board: 2 copper layers, 95.0 x 46.0 mm, 29 parts (0 on the bottom side), 23 nets.

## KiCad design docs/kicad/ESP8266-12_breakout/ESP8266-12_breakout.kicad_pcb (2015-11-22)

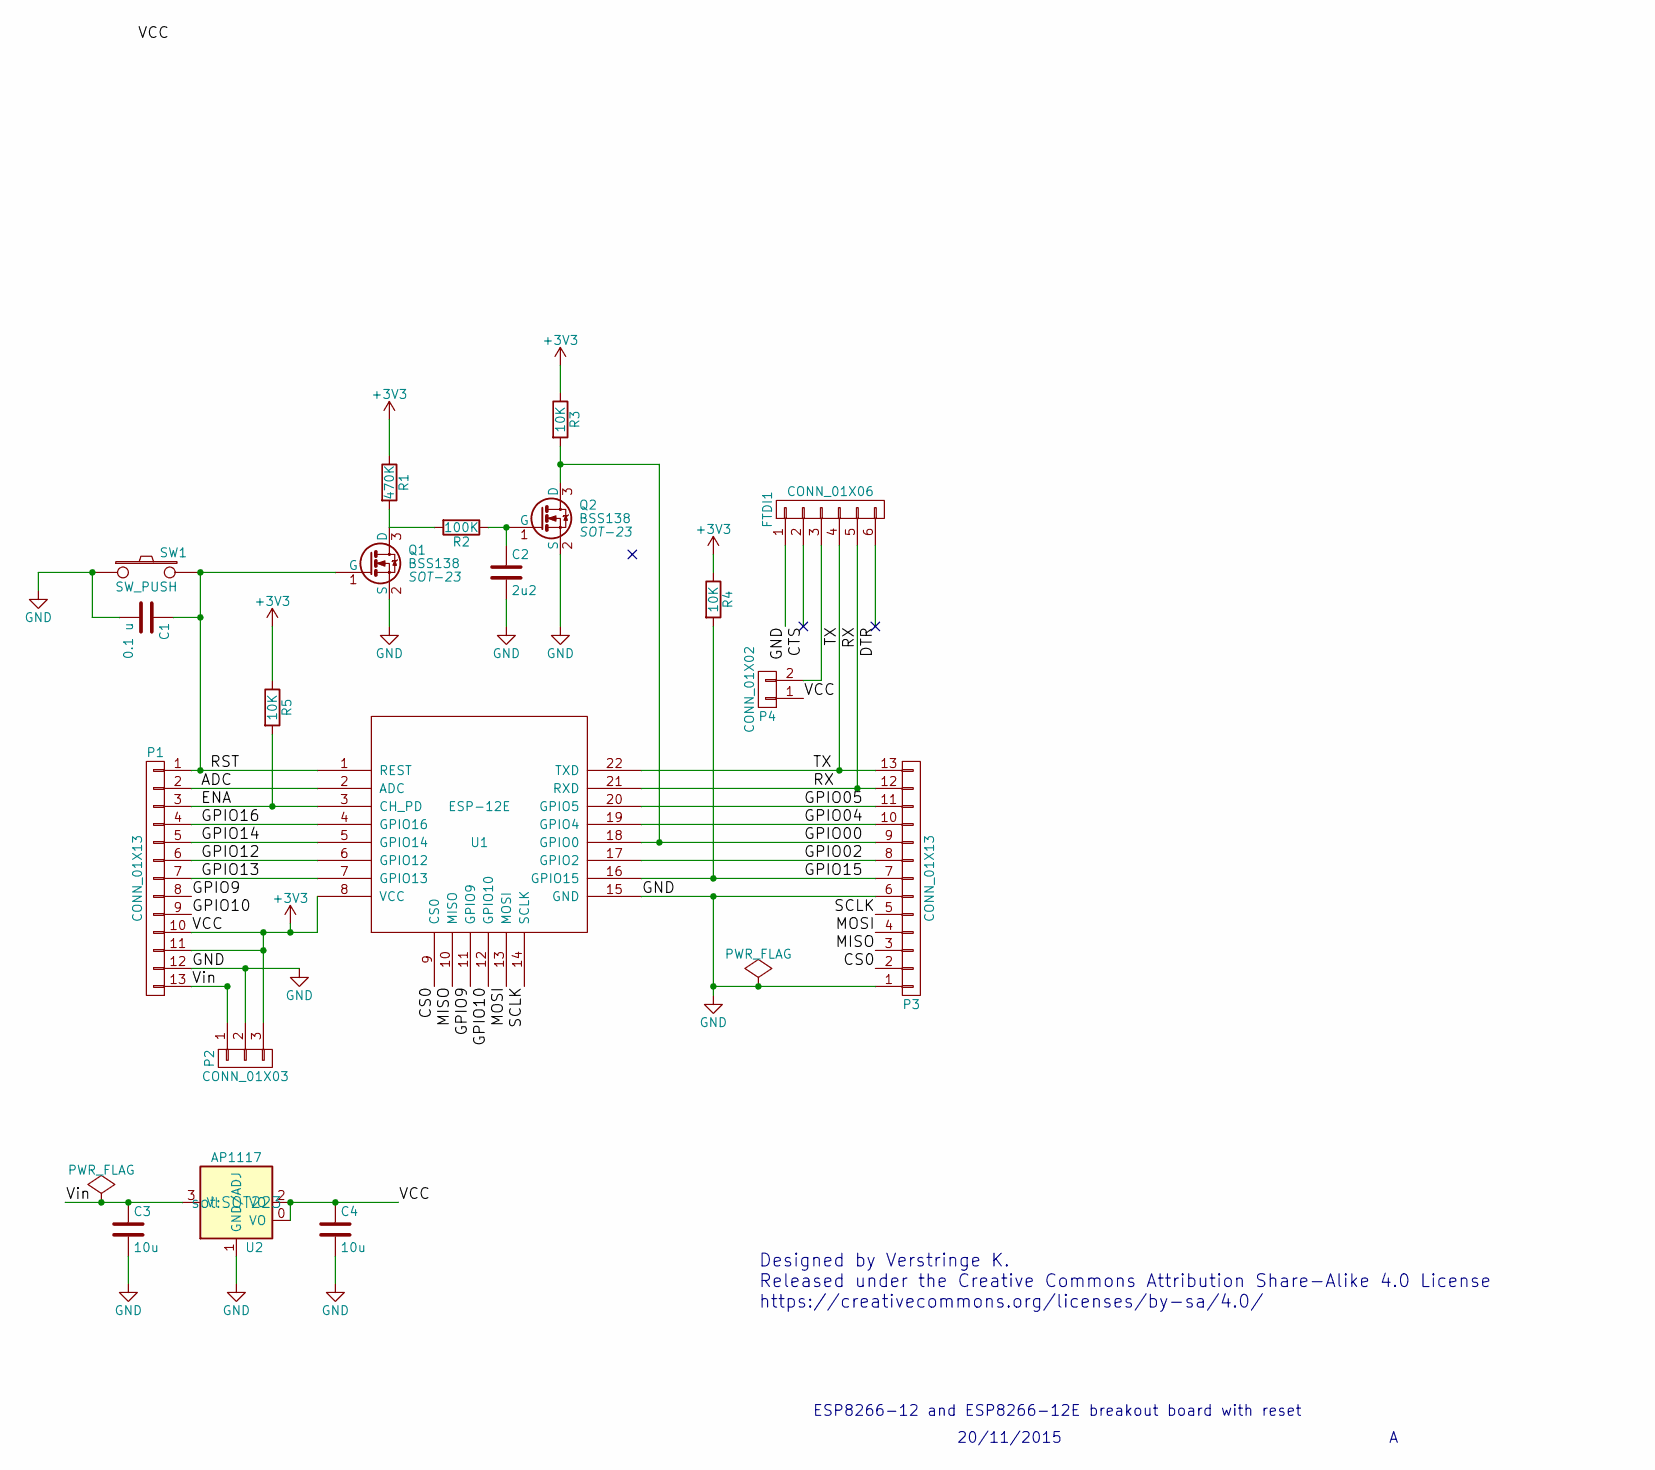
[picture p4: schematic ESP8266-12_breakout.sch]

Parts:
C1: 0.1 u; C_1206_HandSoldering
C2: 2u2; C_1206_HandSoldering
C3, C4: 10u; C_1206_HandSoldering
FTDI1: CONN_01X06; Pin_Header_Straight_1x06
P1, P3: CONN_01X13; Pin_Header_Straight_1x13
P2: CONN_01X03; Pin_Header_Straight_1x03
P4: CONN_01X02; Pin_Header_Straight_1x02
Q1, Q2: BSS138; SOT-23
R1: 470K; R_1206_HandSoldering
R2: 100K; R_1206_HandSoldering
R3, R4, R5: 10K; R_1206_HandSoldering
SW1: SW_PUSH; SW_SPST_EVPBF
U1: ESP-12E
U2: AP1117; SOT223

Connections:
+3V3: C4.1, P1.10, P1.11, P2.3, P4.1, R1.1, R3.1, R4.1, R5.1, U1.8 (VCC), U2.0 (VO), U2.2 (VO)
/ADC: P1.2, U1.2 (ADC)
/CS0: P3.2, U1.9 (CS0)
/CTS: FTDI1.2
/DTR: FTDI1.6
/ENA: P1.3, R5.2, U1.3 (CH_PD)
/GPIO00: P3.9, Q2.3 (D), R3.2, U1.18 (GPIO0)
/GPIO02: P3.8, U1.17 (GPIO2)
/GPIO04: P3.10, U1.19 (GPIO4)
/GPIO05: P3.11, U1.20 (GPIO5)
/GPIO9: P1.8, U1.11 (GPIO9)
/GPIO10: P1.9, U1.12 (GPIO10)
/GPIO12: P1.6, U1.6 (GPIO12)
/GPIO13: P1.7, U1.7 (GPIO13)
/GPIO14: P1.5, U1.5 (GPIO14)
/GPIO15: P3.7, R4.2, U1.16 (GPIO15)
/GPIO16: P1.4, U1.4 (GPIO16)
/MISO: P3.3, U1.10 (MISO)
/MOSI: P3.4, U1.13 (MOSI)
/RST: C1.1, P1.1, Q1.1 (G), SW1.2, U1.1 (REST)
/RX: FTDI1.5, P3.12, U1.21 (RXD)
/SCLK: P3.5, U1.14 (SCLK)
/TX: FTDI1.4, P3.13, U1.22 (TXD)
/Vin: C3.1, P1.13, P2.1, U2.3 (VI)
GND: C1.2, C2.2, C3.2, C4.2, FTDI1.1, P1.12, P2.2, P3.1, P3.6, Q1.2 (S), Q2.2 (S), SW1.1, U1.15 (GND), U2.1 (GND/ADJ)
unnamed: C2.1, Q2.1 (G), R2.1
unnamed: FTDI1.3, P4.2
unnamed: Q1.3 (D), R1.2, R2.2

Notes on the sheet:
ESP8266-12 and ESP8266-12E breakout board with reset
20/11/2015
Designed by Verstringe K. Released under the Creative Commons Attribution Share-Alike 4.0 License https://creativecommons.org/licenses/by-sa/4.0/

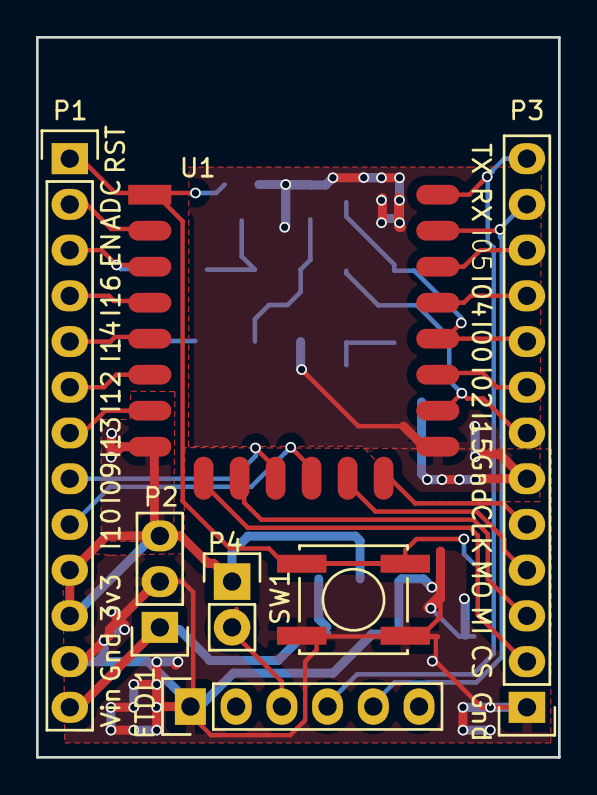
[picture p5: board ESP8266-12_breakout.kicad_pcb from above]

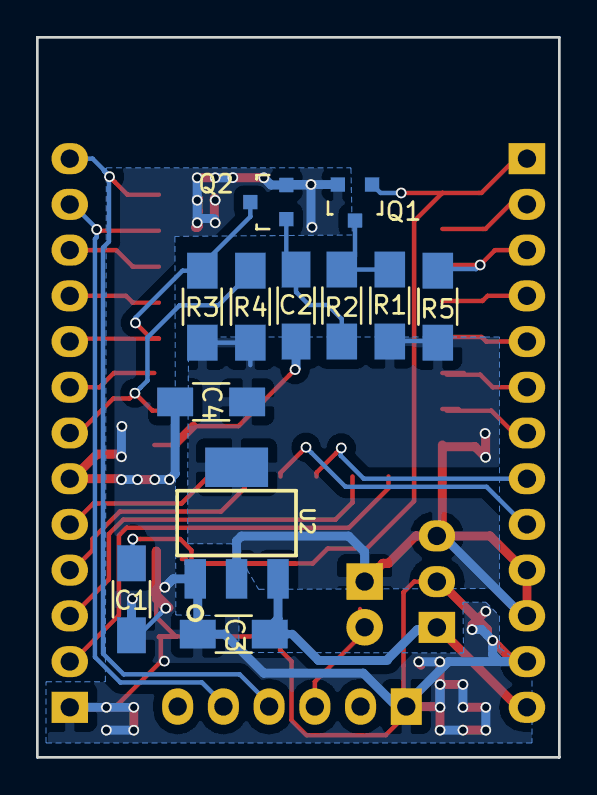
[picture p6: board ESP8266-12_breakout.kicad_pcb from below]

Board: 2 copper layers, 29.0 x 40.0 mm, 19 parts (12 on the bottom side), 26 nets.

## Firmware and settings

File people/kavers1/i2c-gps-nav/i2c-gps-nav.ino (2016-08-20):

/*******************************************************************************************************************************
 * I2CGPS  - Inteligent GPS and NAV module for MultiWii by EOSBandi
 * V2.2   
 *
 * This program implements position hold and navigational functions for MultiWii by offloading caclulations and gps parsing 
 * into a secondary arduino processor connected to the MultiWii via i2c.
 * Once activated it outputs desired banking in a lat/lon coordinate system, which can be easily rotated into the copter's frame of reference.
 *
 * Navigation and Position hold routines and PI/PID libraries are based on code and ideas from the Arducopter team:
 * Jason Short,Randy Mackay, Pat Hickey, Jose Julio, Jani Hirvinen
 * Andrew Tridgell, Justin Beech, Adam Rivera, Jean-Louis Naudin, Roberto Navoni
 * Status blink code from Guru_florida
 * 
 * This program is free software: you can redistribute it and/or modify
 * it under the terms of the GNU General Public License as published by
 * the Free Software Foundation, either version 3 of the License, or
 * any later version. see <http://www.gnu.org/licenses/>
 * This library is distributed in the hope that it will be useful,
 * but WITHOUT ANY WARRANTY; without even the implied warranty of
 * MERCHANTABILITY or FITNESS FOR A PARTICULAR PURPOSE.  See the GNU
 * General Public License for more details.
***********************************************************************************************************************************/

#define VERSION 22                                                         //Software version for cross checking


#include "WireMW.h"
#include "PIDCtrl.h"
#include "PICtrl.h"
#include "LeadFilter.h"


#include "registers.h"                                                    //Register definitions
#include "config.h"

#ifdef __AVR__
  #include <avr/power.h>
#endif


#ifdef NEOPIXEL_FEEDBACK
#include <Adafruit_NeoPixel.h>
#endif

int state_r = 0;
int state_g = 0;
int state_b = 0;

int state2_r = 0;
int state2_g = 0;
int state2_b = 0;

#define REG_MAP_SIZE       sizeof(i2c_dataset)       //size of register map
#define MAX_SENT_BYTES     0x0C                      //maximum amount of data that I could receive from a master device (register, plus 11 byte waypoint data)

#define LAT  0
#define LON  1

///////////////////////////////////////////////////////////////////////////////////////////////////
// Which command I got from the host ? in GPSMode variable
#define GPSMODE_NONAV 0        // no navigation
#define GPSMODE_HOLD  1        // pos hold
#define GPSMODE_WP    2        // wp navigation
///////////////////////////////////////////////////////////////////////////////////////////////////
// Navigation state machine states (nav_mode)
#define NAV_MODE_NONE              0
#define NAV_MODE_POSHOLD           1
#define NAV_MODE_WP                2
// Convert deg*100 to radians
#define RADX100                    0.000174532925  
//Blink feedback, by guru_florida
#define BLINK_INTERVAL  90


// Set up gps lag
#if defined(UBLOX)
  #define GPS_LAG 0.5f			//UBLOX GPS has a smaller lag than MTK and other
#else 
  #define GPS_LAG 1.0f				//We assumes that MTK GPS has a 1 sec lag
#endif  

#if defined(INIT_MTK_GPS)

 #define MTK_SET_BINARY          "$PGCMD,16,0,0,0,0,0*6A\r\n"
 #define MTK_SET_NMEA            "$PGCMD,16,1,1,1,1,1*6B\r\n"
 #define MTK_SET_NMEA_SENTENCES  "$PMTK314,0,1,0,1,0,0,0,0,0,0,0,0,0,0,0,0,0,0,0*28\r\n"
 #define MTK_OUTPUT_4HZ          "$PMTK220,250*29\r\n"
 #define MTK_OUTPUT_5HZ          "$PMTK220,200*2C\r\n"
 #define MTK_OUTPUT_10HZ         "$PMTK220,100*2F\r\n"
 #define MTK_NAVTHRES_OFF        "$PMTK397,0*23\r\n" // Set Nav Threshold (the minimum speed the GPS must be moving to update the position) to 0 m/s  
 #define SBAS_ON                 "$PMTK313,1*2E\r\n"
 #define WAAS_ON                 "$PMTK301,2*2E\r\n"
 #define SBAS_TEST_MODE			 "$PMTK319,0*25\r\n"	//Enable test use of sbas satelite in test mode (usually PRN124 is in test mode)

#endif


typedef struct {
  uint8_t    new_data:1;
  uint8_t    gps2dfix:1;
  uint8_t    gps3dfix:1;
  uint8_t    wp_reached:1;
  uint8_t    numsats:4;
} STATUS_REGISTER;

typedef struct {
  uint8_t command:4;
  uint8_t     wp:4;
} COMMAND_REGISTER;


typedef struct {
 uint8_t     active_wp:4;
 uint8_t     pervious_wp:4;
} WAYPOINT_REGISTER;

typedef struct {
  long      lat;            //degree*10 000 000
  long      lon;            //degree*10 000 000
} GPS_COORDINATES;

typedef struct {
  GPS_COORDINATES position;    //GPS coordinate of the waypoint
  uint16_t        altitude;    //altitude of the waypoint in meters (altitude is relative to the startup altitude)
  uint8_t         flags;       //to be defined
} WAYPOINT;

typedef struct {

//Status and command registers
  STATUS_REGISTER       status;                   // 0x00  status register
  COMMAND_REGISTER      command;                  // 0x01  command register
  WAYPOINT_REGISTER     wp_register;              // 0x02  waypoint register (current, previus)
  uint8_t               sw_version;               // 0x03  Version of the I2C_GPS sw
  uint8_t               res3;                     // 0x04  reserved for future use
  uint8_t               res4;                     // 0x05  reserved for future use
  uint8_t    	 	res5;                     // 0x06  reserved for future use

//GPS & navigation data
  GPS_COORDINATES       gps_loc;                  // current location (8 byte) lat,lon
  int16_t	        nav_lat;                  // The desired bank towards North (Positive) or South (Negative)      1 deg = 100 max 30deg (3000)
  int16_t	        nav_lon;                  // The desired bank towards East (Positive) or West (Negative)        1 deg = 100 max 30deg (3000)
  uint32_t              wp_distance;              // distance to active coordinates  (calculated) in cm
  int16_t               wp_target_bearing;        // direction to active coordinates (calculated)   1deg = 10 / -1800 - 1800
  int16_t               nav_bearing;              // crosstrack corrected navigational bearing 1deg = 10
  int16_t               home_to_copter_bearing;   // 1deg = 10
  uint16_t              distance_to_home;         // distance to home in cm
  uint16_t              ground_speed;             // ground speed from gps m/s*100
  int16_t               altitude;                 // gps altitude
  uint16_t	        ground_course;	          // GPS ground course
  uint16_t              res6;                     // reserved for future use
  uint32_t		time;	                  // UTC Time from GPS
  
//Parameters
  uint8_t		nav_crosstrack_gain;      // Crosstrack gain *100 (1 - 0.01 , 100 - 1)
  uint8_t		nav_speed_min;		  // minimum speed for navigation cm/s
  uint16_t		nav_speed_max;		  // maxiumum speed for navigation cm/s
  uint16_t		nav_bank_max;		  // maximum banking 1deg = 100, 30deg = 3000
  uint16_t		wp_radius;		  // waypoint radius, if we within this radius, then we considered that the wp is reached in cm
  uint8_t               nav_flags;                // navigational flags to be defined
             
  
//PID values
  uint8_t              poshold_p;		  // *100
  uint8_t              poshold_i;		  // *100
  uint8_t              poshold_imax;              // *1

  uint8_t              poshold_rate_p;  	  // *10
  uint8_t              poshold_rate_i;	    	  // *100
  uint8_t              poshold_rate_d;		  // *1000
  uint8_t              poshold_rate_imax;	  // *1

  uint8_t              nav_p;			  // *10
  uint8_t              nav_i;			  // *100
  uint8_t              nav_d;			  // *1000
  uint8_t              nav_imax;		  // *1
  
  WAYPOINT              gps_wp[16];               // 16 waypoints, WP#0 is RTH position

  uint16_t				sonar_distance;

} I2C_REGISTERS;

static I2C_REGISTERS   i2c_dataset;

static GPS_COORDINATES _target;                    //internal target location register

static uint8_t         receivedCommands[MAX_SENT_BYTES];
static uint8_t         new_command;                        //new command received (!=0)


//////////////////////////////////////////////////////////////////////////////
// Variables and controllers

//PID controllers
 
PICtrl	pi_poshold_lat(POSHOLD_P, POSHOLD_I, POSHOLD_IMAX * 100);
PICtrl	pi_poshold_lon(POSHOLD_P, POSHOLD_I, POSHOLD_IMAX * 100);
PIDCtrl	pid_poshold_rate_lat(POSHOLD_RATE_P, POSHOLD_RATE_I, POSHOLD_RATE_D, POSHOLD_RATE_IMAX * 100);
PIDCtrl	pid_poshold_rate_lon(POSHOLD_RATE_P, POSHOLD_RATE_I, POSHOLD_RATE_D, POSHOLD_RATE_IMAX * 100);
PIDCtrl	pid_nav_lat(NAV_P,NAV_I,NAV_D,NAV_IMAX * 100);
PIDCtrl	pid_nav_lon(NAV_P,NAV_I,NAV_D,NAV_IMAX * 100);

LeadFilter xLeadFilter;      // Long GPS lag filter 
LeadFilter yLeadFilter;      // Lat  GPS lag filter 

// used to track the elapsed time between GPS reads
static uint32_t                 nav_loopTimer;
// Delta Time in milliseconds for navigation computations, updated with every good GPS read
static float 			dTnav;

//Actual navigation mode, this needed since we swith to poshold ence arrived at home
static int8_t  nav_mode = NAV_MODE_NONE;            //Navigation mode

static int16_t x_actual_speed = 0;
static int16_t y_actual_speed = 0;
static int32_t last_longitude = 0;
static int32_t last_latitude  = 0;

static int16_t x_rate_d;
static int16_t y_rate_d;

// this is used to offset the shrinking longitude as we go towards the poles
static float	GPS_scaleLonDown;
static float	GPS_scaleLonUp;

// The difference between the desired rate of travel and the actual rate of travel
// updated after GPS read - 5-10hz
static int16_t   x_rate_error;
static int16_t   y_rate_error;
static int32_t	 long_error, lat_error;

// The desired bank towards North (Positive) or South (Negative)
static int16_t	nav_lat;
// The desired bank towards East (Positive) or West (Negative)
static int16_t	nav_lon;

//Used for rotation calculations for GPS nav vector
static float sin_yaw_y;
static float cos_yaw_x;

//Currently used WP
static int32_t  GPS_WP_latitude,GPS_WP_longitude;
static uint16_t GPS_WP_altitude;
static uint8_t  GPS_WP_flags;

//Actual position for calculations
static int32_t  GPS_latitude,GPS_longitude;

////////////////////////////////////////////////////////////////////////////////
// Location & Navigation
////////////////////////////////////////////////////////////////////////////////
// This is the angle from the copter to the "next_WP" location in degrees * 100
static int32_t	target_bearing;
// This is the angle from the copter to the "next_WP" location
// with the addition of Crosstrack error in degrees * 100
static int32_t	nav_bearing;
// saves the bearing at takeof (1deg = 1) used to rotate to takeoff direction when arrives at home
static int16_t  nav_takeoff_bearing;  
////////////////////////////////////////////////////////////////////////////////
// Crosstrack
////////////////////////////////////////////////////////////////////////////////
// deg * 100, The original angle to the next_WP when the next_WP was set
// Also used to check when we pass a WP
static int32_t 	original_target_bearing;
// The amount of angle correction applied to target_bearing to bring the copter back on its optimum path
static int16_t	crosstrack_error;
////////////////////////////////////////////////////////////////////////////////
// The location of the copter in relation to home, updated every GPS read (1deg - 100)
static int32_t	home_to_copter_bearing;
// distance between plane and home in cm
static int32_t	home_distance;
// distance between plane and next_WP in cm
static int32_t	wp_distance;

// used for slow speed wind up when start navigation;
static int16_t waypoint_speed_gov;

// this is the navigation mode what is commanded
static uint8_t GPSMode = GPSMODE_NONAV;          


////////////////////////////////////////////////////////////////////////////////////
// Blink code variables
//
static uint32_t lastframe_time = 0;
static uint32_t _statusled_timer = 0;
static int8_t _statusled_blinks = 0;
static boolean _statusled_state = 0;

#ifdef NEOPIXEL_FEEDBACK
Adafruit_NeoPixel pixels = Adafruit_NeoPixel(NEOPIXEL_NUMPIXELS, NEOPIXEL_PIN, NEO_GRB + NEO_KHZ800);
#endif

////////////////////////////////////////////////////////////////////////////////////
// Sonar variables
//
static uint32_t _sonar_timer = 0;

////////////////////////////////////////////////////////////////////////////////////
// moving average filter variables
//
static uint8_t GPS_filter_index = 0;
static int32_t GPS_filter[2][GPS_FILTER_VECTOR_LENGTH];
static int32_t GPS_filter_sum[2];
static int32_t GPS_read[2];
static int32_t GPS_filtered[2];
static int32_t GPS_degree[2];    //the lat lon degree without any decimals (lat/10 000 000)
static int32_t GPS_lead_latitude, GPS_lead_longitude;

////////////////////////////////////////////////////////////////////////////////////
// this is used to offset the shrinking longitude as we go towards the poles	
// It's ok to calculate this once per waypoint setting, since it changes a little within the reach of a multicopter
//
void GPS_calc_longitude_scaling(int32_t lat)
{
	float rads 			= (abs((float)lat) / 10000000.0) * 0.0174532925;
	GPS_scaleLonDown 		= cos(rads);
	GPS_scaleLonUp 		        = 1.0f / cos(rads);
}

////////////////////////////////////////////////////////////////////////////////////
// Sets the waypoint to navigate, reset neccessary variables and calculate initial values
// Waypoint 16 is a virtual waypoint, it's a pos hold
void GPS_set_next_wp(uint8_t wp_number)
{
  if (wp_number > 16) { return; }      //Do nothing with a wrong WP number

  if (wp_number <=15 ) {
    GPS_WP_latitude  = i2c_dataset.gps_wp[wp_number].position.lat;
    GPS_WP_longitude = i2c_dataset.gps_wp[wp_number].position.lon;
    GPS_WP_altitude  = i2c_dataset.gps_wp[wp_number].altitude;
    GPS_WP_flags     = i2c_dataset.gps_wp[wp_number].flags;
    i2c_dataset.status.wp_reached = 0;    
  } else {
    GPS_WP_latitude  = GPS_latitude;
    GPS_WP_longitude = GPS_longitude;
    GPS_WP_altitude  = 0;
    GPS_WP_flags     = 0;
    i2c_dataset.status.wp_reached = 1;        //With poshold we assume that the wp is reached    
  }    
  
  GPS_calc_longitude_scaling(GPS_WP_latitude);
  
  wp_distance = GPS_distance_cm(GPS_latitude,GPS_longitude,GPS_WP_latitude,GPS_WP_longitude);
  target_bearing = GPS_bearing(GPS_latitude,GPS_longitude,GPS_WP_latitude,GPS_WP_longitude);
  nav_bearing = target_bearing;
  GPS_calc_location_error(GPS_WP_latitude,GPS_WP_longitude,GPS_latitude,GPS_longitude);
  original_target_bearing = target_bearing;
  waypoint_speed_gov = i2c_dataset.nav_speed_min;
  
}

////////////////////////////////////////////////////////////////////////////////////
// Check if we missed the destination somehow
//
static bool check_missed_wp()
{
	int32_t temp;
	temp = target_bearing - original_target_bearing;
	temp = wrap_18000(temp);
	return (labs(temp) > 9000);	// we passed the waypoint by 100 degrees
}
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
void loop() {
  
  static uint8_t GPS_fix_home;
  static uint8_t _command_wp;
  static uint8_t _command;
  static uint32_t _watchdog_timer = 0;
  uint8_t axis;
  uint16_t fraction3[2];

#pragma region while serial available

     while (Serial.available()) {

#if defined(NMEA)
       if (GPS_NMEA_newFrame(Serial.read())) {
#endif 
#if defined(UBLOX)
       if (GPS_UBLOX_newFrame(Serial.read())) {
#endif
#if defined(MTK_BINARY16) || defined(MTK_BINARY19)
       if (GPS_MTK_newFrame(Serial.read())) {
#endif


       // We have a valid GGA frame and we have lat and lon in GPS_read_lat and GPS_read_lon, apply moving average filter
       // this is a little bit tricky since the 1e7/deg precision easily overflow a long, so we apply the filter to the fractions
       // only, and strip the full degrees part. This means that we have to disable the filter if we are very close to a degree line

#pragma region GPS FILTER
       if (i2c_dataset.nav_flags & I2C_NAV_FLAG_GPS_FILTER) {      //is filtering switched on ?

         GPS_filter_index = ++GPS_filter_index % GPS_FILTER_VECTOR_LENGTH;
         
         for (axis = 0; axis< 2; axis++) {
			GPS_degree[axis] = GPS_read[axis] / 10000000;  // get the degree to assure the sum fits to the int32_t
  
	         // How close we are to a degree line ? its the first three digits from the fractions of degree
			//Check if we are close to a degree line, if yes, disable averaging,
			fraction3[axis] = (GPS_read[axis]- GPS_degree[axis]*10000000) / 10000;
	  
			GPS_filter_sum[axis] -= GPS_filter[axis][GPS_filter_index];
			GPS_filter[axis][GPS_filter_index] = GPS_read[axis] - (GPS_degree[axis]*10000000); 
			GPS_filter_sum[axis] += GPS_filter[axis][GPS_filter_index];
			GPS_filtered[axis] = GPS_filter_sum[axis] / GPS_FILTER_VECTOR_LENGTH + (GPS_degree[axis]*10000000);
         }       
         
         if ( nav_mode == NAV_MODE_POSHOLD) {      //we use gps averaging only in poshold mode...
             if ( fraction3[LAT]>1 && fraction3[LAT]<999 ) i2c_dataset.gps_loc.lat = GPS_filtered[LAT]; else i2c_dataset.gps_loc.lat = GPS_read[LAT];
             if ( fraction3[LON]>1 && fraction3[LON]<999 ) i2c_dataset.gps_loc.lon = GPS_filtered[LON]; else i2c_dataset.gps_loc.lon = GPS_read[LON];       
         } else {
             i2c_dataset.gps_loc.lat = GPS_read[LAT];
             i2c_dataset.gps_loc.lon = GPS_read[LON];
         }
       } else { // ignore filtering since it switced off in the nav_flags
           i2c_dataset.gps_loc.lat = GPS_read[LAT];
           i2c_dataset.gps_loc.lon = GPS_read[LON];
       }
       
#pragma endregion

       if (i2c_dataset.status.gps3dfix == 1 && i2c_dataset.status.numsats >= 5) {
          
         lastframe_time = millis();
         //copy the gps coordinates to variables used for calculations
         GPS_latitude = i2c_dataset.gps_loc.lat;
         GPS_longitude = i2c_dataset.gps_loc.lon;

         // It's just for safety since home position must be set from the host
         if (GPS_fix_home == 0) {
            GPS_fix_home = 1;
            i2c_dataset.gps_wp[0].position.lat = GPS_latitude;
            i2c_dataset.gps_wp[0].position.lon = GPS_longitude;
            GPS_calc_longitude_scaling(GPS_latitude);  //need an initial value for distance and bearing calc
         }
         //dTnav calculation
         //Time for calculating x,y speed and navigation pids
		 dTnav = (float)(millis() - nav_loopTimer)/ 1000.0;
		 nav_loopTimer = millis();
         // prevent runup from bad GPS
		 dTnav = min(dTnav, 1.0);  

         _watchdog_timer = millis();  //Reset watchdog timer
          
         //calculate distance and bearings for gui and other stuff continously this is independent from navigation
         i2c_dataset.distance_to_home = GPS_distance_cm(GPS_latitude,GPS_longitude,i2c_dataset.gps_wp[0].position.lat,i2c_dataset.gps_wp[0].position.lon);
         i2c_dataset.home_to_copter_bearing = GPS_bearing(i2c_dataset.gps_wp[0].position.lat,i2c_dataset.gps_wp[0].position.lon,GPS_latitude,GPS_longitude);
         //calculate the current velocity based on gps coordinates continously to get a valid speed at the moment when we start navigating
         GPS_calc_velocity(GPS_latitude,GPS_longitude);        
          
         if (GPSMode != 0){    //ok we are navigating 
            //do gps nav calculations here   

#if defined(GPS_LEAD_FILTER)
             wp_distance = GPS_distance_cm(GPS_lead_latitude,GPS_lead_longitude,GPS_WP_latitude,GPS_WP_longitude);
             target_bearing = GPS_bearing(GPS_lead_latitude,GPS_lead_longitude,GPS_WP_latitude,GPS_WP_longitude);
             GPS_calc_location_error(GPS_WP_latitude,GPS_WP_longitude,GPS_lead_latitude,GPS_lead_longitude);
#else 
             wp_distance = GPS_distance_cm(GPS_latitude,GPS_longitude,GPS_WP_latitude,GPS_WP_longitude);
             target_bearing = GPS_bearing(GPS_latitude,GPS_longitude,GPS_WP_latitude,GPS_WP_longitude);
             GPS_calc_location_error(GPS_WP_latitude,GPS_WP_longitude,GPS_latitude,GPS_longitude);
#endif

             switch (nav_mode) {
              case NAV_MODE_POSHOLD: 
                //Desired output is in nav_lat and nav_lon where 1deg inclination is 100 
	        GPS_calc_poshold(long_error, lat_error);
                break;
               case NAV_MODE_WP:
		int16_t speed = GPS_calc_desired_speed(i2c_dataset.nav_speed_max, true);      //slow navigation 
		// use error as the desired rate towards the target
		GPS_calc_nav_rate(speed);

                // Are we there yet ?(within 2 meters of the destination)
	        if ((wp_distance <= i2c_dataset.wp_radius) || check_missed_wp()){         //if yes switch to poshold mode
                     nav_mode = NAV_MODE_POSHOLD;
                     //set reached flag
                     i2c_dataset.status.wp_reached = 1;
                   } 
               break;               
              } //switch nav mode
           } // if GPSmode!=0  
           // update i2c dataset from nav 
           GPS_update_i2c_dataset();
        } else {      // we does not have 3d fix or numsats less than 5 , stop navigation
                 nav_lat = 0;
                 nav_lon = 0;
                 GPSMode = GPSMODE_NONAV;
                 nav_mode = NAV_MODE_NONE;
                 wp_distance = 0;
                 i2c_dataset.distance_to_home = 0;
                 i2c_dataset.home_to_copter_bearing = 0;
                 GPS_update_i2c_dataset();
               }
        // have new data at this point anyway
       i2c_dataset.status.new_data = 1;

      } // new frame
     } //while 
#pragma endregion

blink_sonar_update();
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

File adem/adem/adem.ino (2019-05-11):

/*
 * This file is part of the ADEM project.
 *
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
 * Copyright 2016 Dag Wieers, Lieven Blancke, Koen Verstringe
 *
 */

//#define DEMO 1
 
#include <TickerSchedlr.h>
#include <DNSServer.h>
#include <ESP8266WebServer.h>
#include <ESP8266mDNS.h>

#include <accelero_MPU6050.h>
#include <barometer_BMP085.h>
#include <battery_lipo.h>
#include <buzzer_passive.h>
//#include <gps_SwSerial.h>
#include <gps_I2C.h>
#include <humidity_HTU21D.h>
#include <led_NeoPixel.h>
#include <particulate_PPD42.h>
#include <wifi_WiFiManager.h>
#include "store_and_forward.h"


#define PM1_PIN 12
#define PM25_PIN 13	// The PM25 we use in naming everywhere actually means PM2.5!
#define GPS_TX_PIN 16
#define GPS_RX_PIN 4
#define GPS_BAUD 9600
#define NEOPIXEL_PIN 0
#define SERIAL_BAUD 74880

// defines for debugging purposes (un)comment where needed
// #define TELNET
#define DEBUG
#define set_breakmode 1
#undef TELNET

#ifdef TELNET

#include "RemoteDebug.h"        //https://github.com/JoaoLopesF/RemoteDebug
extern void TelnetSetup();

RemoteDebug Telnet;

// Host name

#define HOST_NAME "rem-debug" // PLEASE CHANGE IT

// Time

uint32_t mLastTime = 0;
uint32_t mTimeSeconds = 0;
#endif

#ifdef DEBUG
  #ifdef TELNET
    #define __LOG(msg) Telnet.print(msg)
    #define __LOGLN(msg) Telnet.println(msg)
    #define __LOGHEX(msg) Telnet.print("0x");Telnet.print(msg,HEX);Telnet.print(" ")
  #else
    #define __LOG(msg) Serial.print(msg)
    #define __LOGLN(msg) Serial.println(msg)
    #define __LOGHEX(msg) Serial.print("0x");Serial.print(msg,HEX);Serial.print(" ")
  #endif
#else
#define __LOG(msg)
#define __LOGLN(msg)
#define __LOGHEX(msg) 
#endif

// Different states of the program
enum state_t {
  STATE_START,
  STATE_DEMO,
  STATE_SLEEP,
  STATE_CONFIG,
  STATE_GPSTEST,
  STATE_COLLECT,
  STATE_WIFITEST,
  STATE_UPLOAD,
  STATE_RESET,
  STATE_LOW_POWER,
};
char *states[] {
  "START",
  "DEMO",
  "SLEEP",
  "CONFIG",
  "GPSTEST",
  "COLLECT",
  "WIFITEST",
  "UPLOAD",
  "RESET",
  "LOW POWER",
};
state_t prev_state = STATE_START;
state_t state = STATE_START;
bool wififail = false;
bool demoflag = false;
uint16_t sensors_detected = 0;
uint16_t sensors_config = -1;

/*#ifdef DEMO
const char *mdnsname = "adem";  // Used by mDNS. Try http://adem.local/
DNSServer dnsserver;
ESP8266WebServer webserver(80);
IPAddress apIP(192, 168, 4, 1);
state_t next_state = STATE_DEMO;
#else // DEMO*/
state_t next_state = STATE_START;
//#endif // DEMO

// DEBUG input
class Debug {
public:
  boolean gpsready = false;
  boolean moving   = false;
  boolean shaken   = false;
  boolean wifi     = false;
#ifdef set_breakmode
  boolean breakmode = true ;
#else
  boolean breakmode = false;
#endif  
  boolean breakcont = false;
} debug;

volatile bool interrupt_flag;

storeAndForwardBuf buffer(10000);

// Objects for all the sensor libraries
MPU6050Sensor accelerometer;
BMP085Sensor barometer;
LipoBattery battery;
PassiveBuzzer buzzer;
//SwSerialGPS gps = SwSerialGPS(GPS_RX_PIN, GPS_TX_PIN, GPS_BAUD);
I2CGps gps = I2CGps();
HTU21DFSensor humidity;
NeoPixelLed led = NeoPixelLed(1, NEOPIXEL_PIN, NEO_GRB + NEO_KHZ800);
PPD42Sensor particulate(PM1_PIN, PM25_PIN);
char SSID[20];
const int SCHED_MAX_TASKS = 100;
TickerSchedlr *schedule = NULL;
WiFiManagerWifi wifimngr;
myWiFiManagerParameter * custom_config;
myWiFiManagerParameter * demo;
myWiFiManagerParameter * sensors_parm;

String page = "";

// FIXME: Since brightness does not seem to work, use "darker" colors
// Colors
uint32_t black = led.Color(0, 0, 0);
uint32_t white = led.Color(127, 127, 127);
uint32_t red = led.Color(127, 0, 0);
uint32_t orange = led.Color(127, 63, 0);
uint32_t yellow = led.Color(127, 127, 0);
uint32_t green = led.Color(0, 127, 0);
uint32_t light_blue = led.Color(0, 127, 127);
uint32_t blue = led.Color(0, 0, 127);
uint32_t purple = led.Color(63, 0, 127);

uint32_t _lst_msg = 0;
uint32_t ts =0;
uint32_t i2c_ts = 0;
uint32_t i2c_status = 0;

unsigned char twi_sda, twi_scl;

uint32_t colors[] = {
  red,
  light_blue,
  black,
  yellow,
  orange,
  green,
  purple,
  blue,
  white,
  black
};

uint16_t led_state = 0;

// Tasks
TickerTask *accelerometer_task = NULL;
TickerTask *barometer_task = NULL;
TickerTask *battery_task = NULL;
TickerTask *gps_task = NULL;
TickerTask *humidity_task = NULL;
TickerTask *particulate_task = NULL;
TickerTask *upload_task = NULL;

// TASKS
void accelerometer_run(void *) {
//  __LOGLN(":accelerometer: -> Check moving/shaken");
  //accelerometer.read();
  //Serial.println(accelerometer.report());

  // process normal accel data in logging.
  // MPU will store data internally in its FIFO so we have to loop
  while (accelerometer.hasData()) {
    accelerometer.read();
    buffer.write((char *)accelerometer.dataToBuffer(), accelerometer.dataBufferSize());
    yield(); // we can have lots of data stpp WDT crashes
   __LOGLN(accelerometer.report());
  }
}

void barometer_run(void *) {
  barometer.read();
  buffer.write((char *)barometer.dataToBuffer(), barometer.dataBufferSize());
  __LOGLN(barometer.report());
}

void battery_run(void *) {
  battery.read();
  buffer.write((char *)battery.dataToBuffer(), battery.dataBufferSize());
//  __LOGLN(battery.report());
}

void gps_run(void *) {
  gps.read();
  if (gps.ready) {
    buffer.write((char *)gps.dataToBuffer(), gps.dataBufferSize());
    __LOGLN(gps.report());
  }
}

void humidity_run(void *) {
  humidity.read();
  buffer.write((char *)humidity.dataToBuffer(), humidity.dataBufferSize());
  __LOGLN(humidity.report());
}

void particulate_run(void *) {
  particulate.read();
  buffer.write((char *)particulate.dataToBuffer(), particulate.dataBufferSize());
  __LOGLN(particulate.report());
}
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

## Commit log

2015-07-28 added arduino folder with last year's first prototype code
2015-08-05 4 meetwaarden overslaan en het gemiddelde van de rest sturen naar ThingSpeak
2015-10-30 watchdog timer gaf stack trace errors, vermeldingen hiervan werden verwijderd
    [shadowandyGPS.ino]
2015-11-04 Copy orf plerup/espsoftwareserial Implementation of the Arduino software serial for ESP8266
2015-11-11 Code opgekuist, variabele namen verduidelijkt, ringbuffer geeft nog problemen
    [shadowandyGPS.ino]
2015-11-11 small fixes to variable names, function declarations
    [shadowandyGPS.ino]
2015-11-20 serial.swap, read gps data in main loop, fixed sending buffer
    [shadowandyGPS.ino]
2015-11-21 initial KICAD design for ADEM pcb
    [ADEM.kicad_pcb, ADEM.sch, ESP8266-12_breakout.kicad_pcb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]
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2015-12-02 changed year parameter for FormatDate fromt uint8_t to uint16_t, removed Serial.Swap() in favour of SoftwareSerial for GPS communication
    [shadowandyGPS.ino]
2015-12-09 changed PIN numbers, initialize formatDate and formatTime, toggle LED with interrupt
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2015-12-09 ringbuffer output geeft nu na eerste regel geen nullen meer uit bij print(F("text")) werd de F macro verwijderd om mogelijke oorzaak van crashes op te sporen.
    [shadowandyGPS.ino]
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2016-02-24 moved adem_main/Ppd42 to libraries/Ppd42 moved adem_main/Sensor to libraries/Sensor added initial minimal library usage to adem_main/adem_main.ino explained library usage in libraries/README.md
2016-02-24 added link to How to write libraries for the Arduino
2016-03-02 corrected millis to micros
2016-03-02 ReadPM now returns ppm in unsigned long in stead of double float Clarified variable names to use Millis or Micros in stead of Time Added detachInterrupt to end() Moved the micros() function up in the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
2016-03-07 reworked schedule now using singleton pattern for scheduler and factory methods for tasks so that only pointer to tasks exists
    [TestSchedlr.ino]
2016-03-10 Moved the Hardware and Firmware sections in the README.md to separate files in their respective folders (hardware, arduino).
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2016-03-19 Disable inverted signaling for our GPS component
    Lost 2 hours understanding why I got garbage data from SoftwareSerial, and not from the pin directly.
    [shadowandyGPS.ino]
2016-03-20 added tickerSchedlr to the library section Humidity sensor and barometric senser added
2016-03-23 Add Arduino Jam test to personal directory
    [esp8266_jam.ino]
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2016-04-10 Fixing the Travis CI builds (but also Arduino builds) by moving the libraries out of the project tree
2016-04-10 Added newer Arduino Jam code
    [esp8266_jam2.ino]
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2016-04-13 Correct the Serial interface pins (mixed up with GPS)
    [adem.ino]
2016-04-13 Modify existing code using the new pin assignments and library code
2016-04-13 Move NeoPixel to D5 (same as on-board led), Add GPS RX and I2C pins
2016-04-14 Moving KICAD files into docs/ (the hardware/ directory was confusing Travis CI Sketch)
    [ADEM.kicad_pcb, ADEM.sch, ESP8266-12_breakout.kicad_pcb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]
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2016-04-15 Implemented complete pseudo code and LED indication
    Conditions are not being tested, but logic is written to go into COLLECT state immediately.
2016-04-15 Initial commit of the led_NeoPixel library
    Compiles fine, but fails to work.
    Setup works fine, LED does not change color.
    Once loop() starts or at end of setup() things halt with no output.
    [led_test.ino]
2016-04-15 Added the new led_NeoPixel library but disable the code (since it doesn't work)
    [adem.ino]
2016-04-15 Found the culprit, we didn't call NeoPixel.begin() from the wrapper
    [adem.ino]
2016-04-15 Added preliminary GPS code, doesn't compile though
    The main adem.ino was updated, but with commented pieces for GPS.
    [adem.ino]
2016-04-15 Small clarification, this is the Sparkfun Development board
2016-04-16 fixed use of SoftwareSerial and TinyGPSPlus libraries in SwSerialGPS library
    [adem.ino]
2016-04-16 Redesign state management, create state and transition functions
    We now have different state functions and transition functions.
    The state management is now done by 2 different case constructions.
    One for handling the state, and one for handling the transitions.
    [adem.ino]
2016-04-16 Added Makefile to build code and flash your device
2016-04-16 Fixed te scheduler problem (do not instantiate in global scope)
    [adem.ino]
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2016-04-16 Ensure JSON output is a one-liner (sensors data is pretty limited anyway)
2016-04-16 Control LED from main loop (only one statement for all states)
2016-04-16 Add FIXME related to setBrightness not working properly
    [adem.ino]
2016-04-16 Fix the humidity/temperature output, and reindent
    [adem.ino]
2016-04-16 Added FIXME for barometer.begin() now that we know when it fails
    [adem.ino]
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2016-04-17 Update the TODO list to current project status
2016-04-17 Add altitude and speed to sensor data output
2016-04-22 Ignore arduino15 symlink, update Makefile to support MacOSX
2016-04-22 Cosmetic changes, ensure START state has red LED
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2016-04-23 Prefix states, added stub classes for accelerometer and buffer, add test wifiap code
2016-04-23 Add missing wificlient stub
    [adem.ino]
2016-04-24 Added buzzer_passive code, but disabled (shares PIN 5 with NeoPixel)
    [adem.ino, buzzer_test.ino]
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2016-04-27 Fix correct transition (should have been fixed previously)
    [adem.ino]
2016-05-07 Added references for I2C info on GPS to accommodate the UART->I2C hack
2016-05-07 removed measured from sensordata and moved it to the class data to save some space in the buffering
2016-05-11 changed: store_And_Forward.h to store_and_forward.h => gave compile error in OSX changed: include <..\..\Sensor\Sensor.h> to #include <../../Sensor/Sensor.h> => gave compile error in OSX
    [adem.ino]
2016-06-15 Assorted changes
    - Remove the StubBuffer now that we have a real buffer
    - Add a 500ms delay in the sleep state
    - Disconnect WIFI to improve battery consumption
    - Move upload_task() creation/suspension to state transition
    - Added some hints that state machine transitioned into sleep state
    - Added the Chip ID in the WIFI AP SSID
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2016-08-19 upper-lower-case linus issue ;-)
2016-08-20 Fix a small typo
    [adem.ino]
2016-08-20 I2C-GPS example code
    [u-blox-config.ublox.txt]
2016-08-20 stripped I2C-GPS
    [u-blox-config.ublox.txt]
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2016-08-21 Fix SSID for AP mode
    [adem.ino]
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2016-08-30 updated pin assignments and some fixes
2016-08-31 added -DDEBUG_OUTPUT=Serial for workaround not defined in Library https://github.com/esp8266/Arduino/pull/2279
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2016-09-22 Demo mode (#17)
    - Enables WIFI_AP and WebServer
    - Includes hard-coded demo HTML/javascript (adem/demo.h)
    - Webserver exports sensor data to HTML page as JSON
2016-09-25 Implementation of a captive portal (#19) (#21)
    This commit implements the captive portal idea.
    When you associate with the WIFI AP, you will get a logon pop-up, which
    gets you directly to the ADEM info page. And if you continue, you will
    get forwarded to http://adem.local/ whatever URL your browser targets.
    This fixes #19
    [adem.ino]
2016-09-28 Updated Arduino to v1.6.12 (#23)
    * Ensure Travis doesn't complain
    * Updated Arduino to v1.6.12
2016-10-10 Use uint64_t for PPM information (#29)
    Also make ppd42_test easy to build for Arduino Uno
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2016-10-10 Add support for building for Arduino Uno (#31)
    This is a temporary fix until we have moved the dedicated Arduino Uno
    code from people/kavers1 to the project's root.
2016-10-11 I2C gps with correct register map
    [registers.h]
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2016-10-15 fixed date problem moved to seperate path
    [u-blox-config.ublox.txt]
2016-10-15 removed personal development space
    [u-blox-config.ublox.txt]
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2016-10-19 Add delay in demo-loop (improves WIFI stability)
    [adem.ino]
2016-10-19 Reorganize codebase
    - put adem/ and i2c-slave/ on the same level
    - move platformio.ini to adem/
    - move libraries/ to adem/
    - update Travis CI
    - update Makefile to support i2c-slave and adem codebase
    - fix a casing problem in I2Cgps.cpp
    [u-blox-config.ublox.txt]
2016-10-20 Learn Makefile to understand different HWTYPEs
    Since we now have 2 microcontrollers and 2 codebases for each
    respectively, we need to teach `make` which hardware is used for which
    project.
    - i2c-slave/i2c-slave.ino -> Arduino Pro Mini
    - everything else -> Sparkfun Thing
    But this can be overriden using eg. HWTYPE=uno
    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
2016-11-16 Rename PM10 consistently to PM1 to avoid confusion (#39)
    [adem.ino, esp8266_gps.ino, esp8266_jam.ino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]
2016-11-17 Fix the speed of the Arduino Pro Mini (#40)
2016-11-17 Adem indent (#42)
    * Reformatted codebase
    Functionally the same, but properly indented.
    Somewhat more debugging statements.
    * Indentation fixes
    [adem.ino]
2016-11-19 corrected state machine
    demo code for state machine
    tap on the back to wake it.
    Keep still to stall
    [Tap_dmp_example.ino]
2016-11-20 only fill measuredData when I2C GPS initialization was OK, extra debug info
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2016-11-20 Small fix -- should wait for Travis before merging (#46)
    * Restructured code, 100kHZ I2C
    * Small fix -- should wait for Travis before merging
    [adem.ino]
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2017-01-22 fixing I2C read problem 32 byte limit
    [i2c-slave.ino, i2c_gps_registers.h, twiMW.c]
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2017-01-30 fixed wdt on serial gps comm
    [i2c-slave.ino]
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2017-02-08 make monitor works after starting and exiting serial monitor in Arduino IDE
2017-02-08 GPS communication and querying fixes
    [adem.ino]
2017-02-09 added gps ready status. compiles but not tested yet
    wd_timestamp van 32 bit ipv 16 bit
    bij faling wdt wordt de dataset niet meer gereset naar 0 maar enkel de
    ready status vlag afgezet
2017-02-12 update status led blinks
    1 blink for general looping (detects hanging of arduino)
    2 blinks if gps fix is available
    3 blinks if gps fix and I2C communication
    [i2c-slave.ino]
2017-03-08 replace I2CDEV reads
    since available() is different in the arduino and the ESP world we have
    to convert the readBytes calls
2017-03-15 Add correct serial device and baud rate
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2017-04-20 remote debug capabilities
    Dit is een library die remote debug over telnet toelaat. Vermoedelijk
    hebben we die niet nodig in een final release
2017-04-20 update wifimanager
    wifimanager moet de eigen implementatie van de wifi manager gebruiken
    zodat 4 access points kunnen gestockeerd worden
2017-04-30 bug fixes in wifimanager and master ino
    [adem.ino]
2017-05-01 bug fixed for accelero and store and forward
    [adem.ino]
2017-05-02 store and forward fixes and sensor virtual reporting
    [adem.ino]
2017-05-03 I2C_GPS bug fix
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2017-05-11 fixed ID problem for store and forward
    [adem.ino]
2017-05-24 buffered report for GPS was missing
    [adem.ino]
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2017-11-24 #56 initial attempt to add DEMO state
    #56
    Removed the conditional DEMO flag
    #54 I2C scanner added and devices stored at startup
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2017-12-04 Add both adem and i2c-gps projects in parallel (#62)
    * Clean up CI scripts
    * Add both adem and i2c-gps projects in parallel
    Testing if this works better.
    Now the adem and i2c-gps builds are in parallel.
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2019-05-11 Tel net wifi (#73)
    * test heap size and delete dynamic values in webserver
    * added html for redirection
    * fixed escaped qutoes
    * type cast
    * no persenal info tracking
    * typedasts
    [adem.ino]
2019-05-27 Pr/70 (#77)
    * Changed wording in the readme to air quality estimate
    New address of Timelab
    ESP32?
    * i2c dev update
    * type casting
    * type casts
